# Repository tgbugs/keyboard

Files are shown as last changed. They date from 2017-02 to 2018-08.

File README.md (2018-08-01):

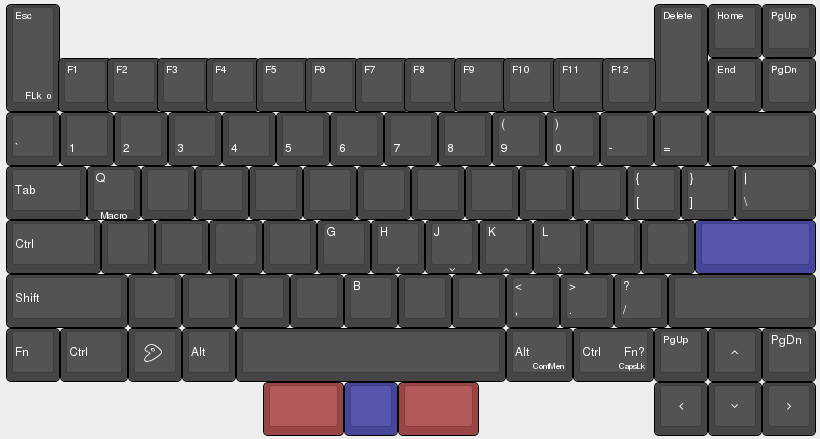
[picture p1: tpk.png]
current layout

# kicad libs and mods needed
https://github.com/tmk/kicad_lib_tmk.git
https://github.com/tmk/keyboard_parts.pretty
https://github.com/stormbard/Keyboard.pretty.git
https://github.com/XenGi/kicad_teensy.git
# use this guide
https://github.com/ruiqimao/keyboard-pcb-guide
# keyboard layout editor
https://github.com/swill/kb_builder
http://www.keyboard-layout-editor.com
# teensy setup on gentoo
Need dev-embedded/teensyduino and dev-embedded/teensy_loader_cli, working ebuilds in https://github.com/tgbugs/tgbugs-overlay.
# freerout is basically a necisity use this repo
https://github.com/nick-less/freerouting
Some setup needed to get maven to play nice. Just read the errors.
# gerbv
Before shipping out the gerber files do a once over in something other than kicad. `emerge gerbv`

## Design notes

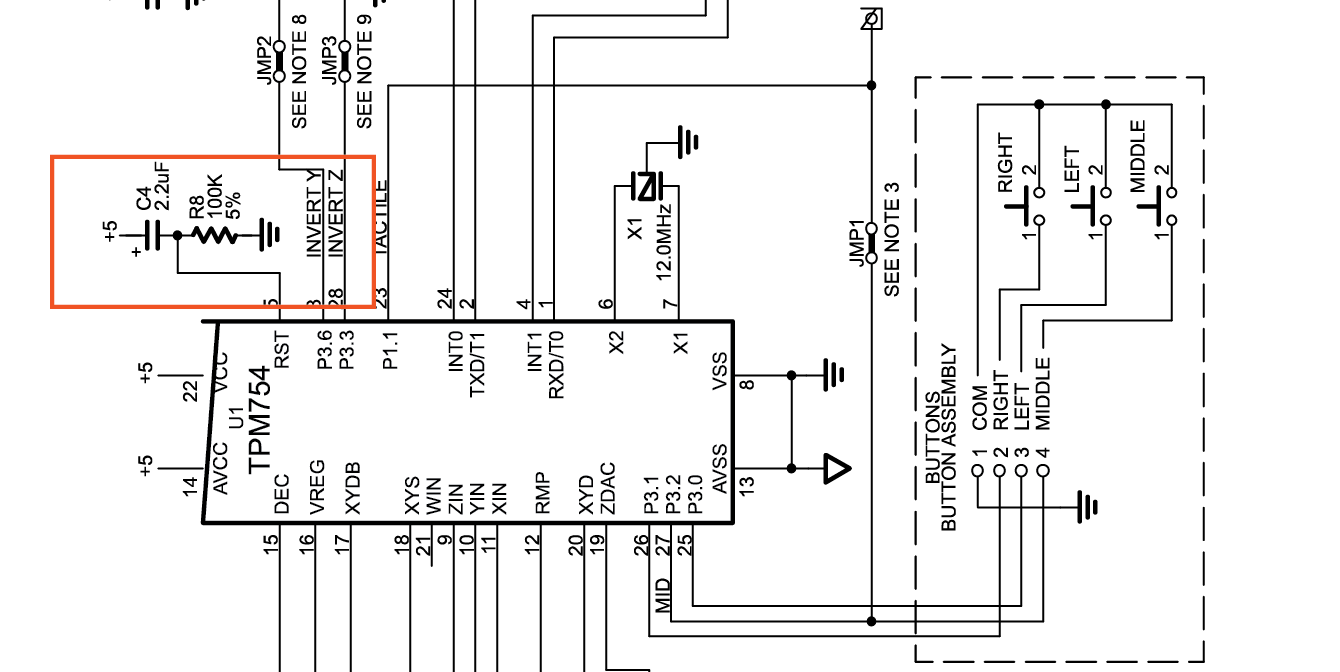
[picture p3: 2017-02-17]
doc/schematics/DSA1.png

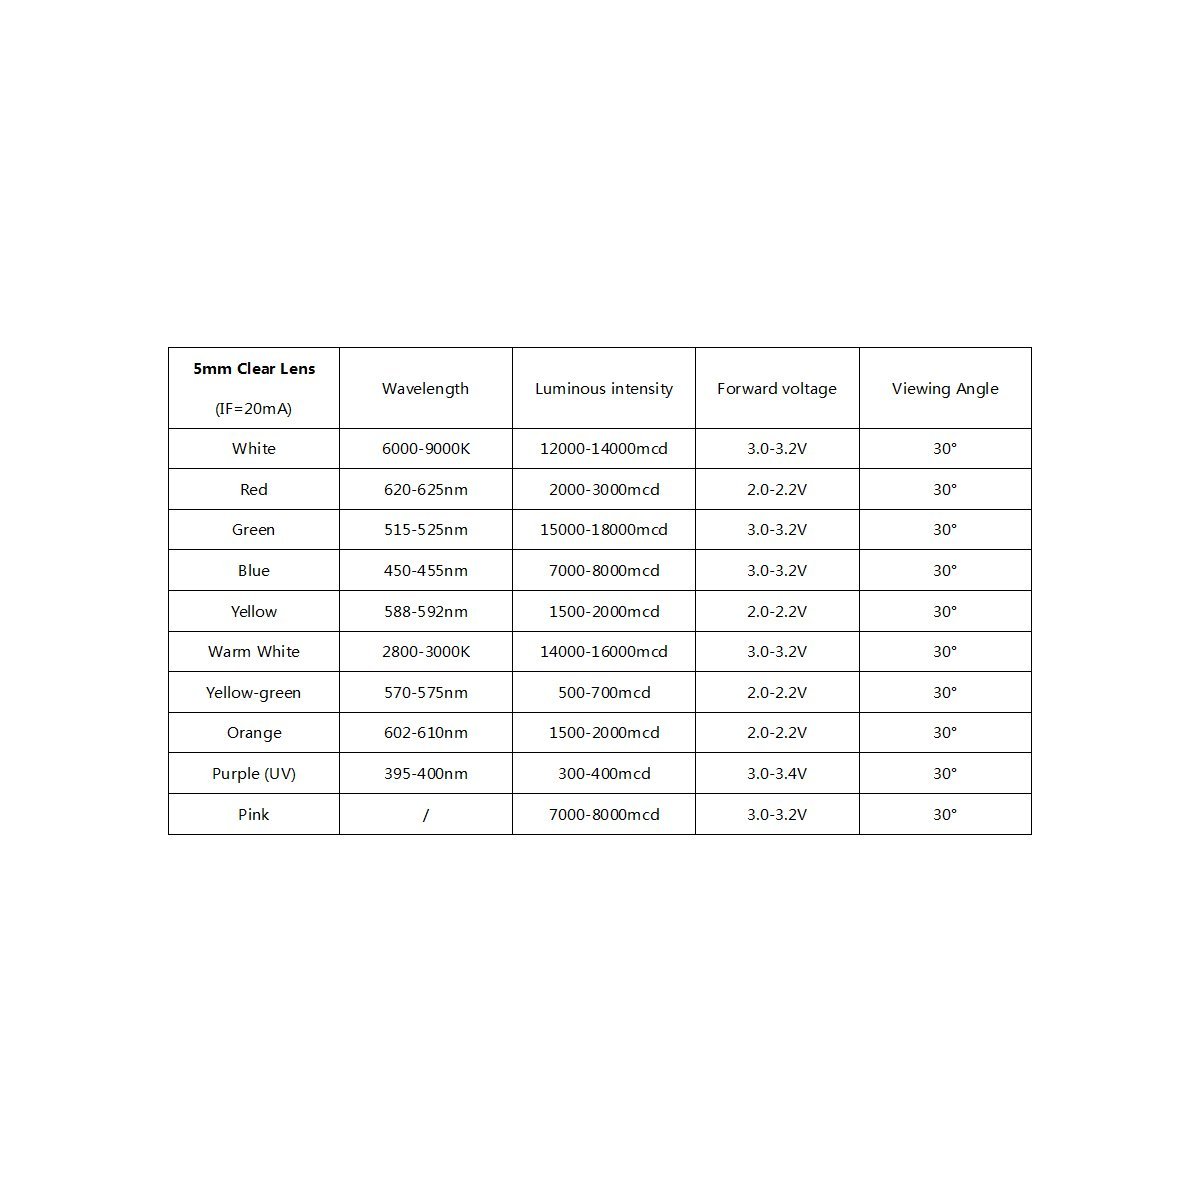
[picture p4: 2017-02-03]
doc/schematics/61HGZPv6i1L._SL1200_.jpg

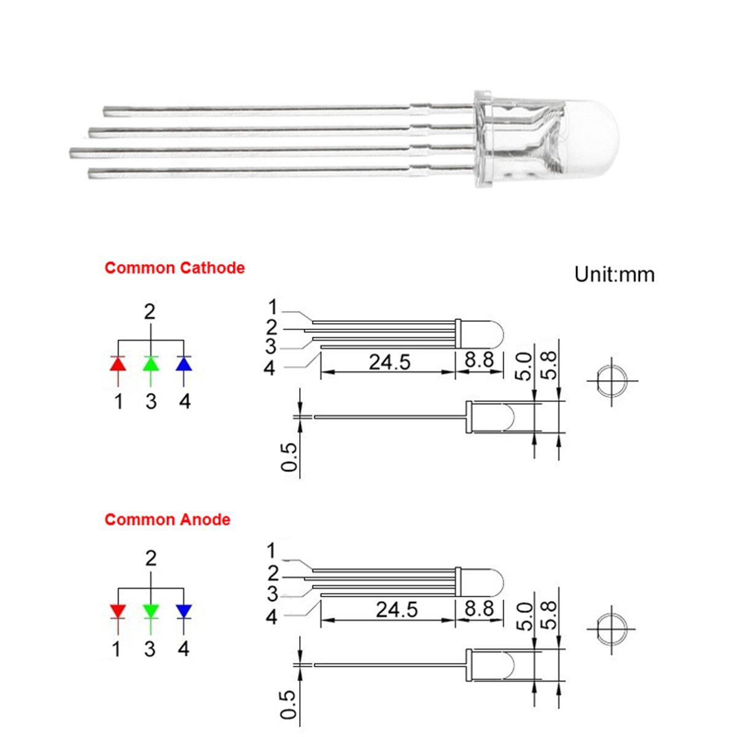
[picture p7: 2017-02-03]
doc/schematics/61A5xmcpJOL._SL1200_.jpg

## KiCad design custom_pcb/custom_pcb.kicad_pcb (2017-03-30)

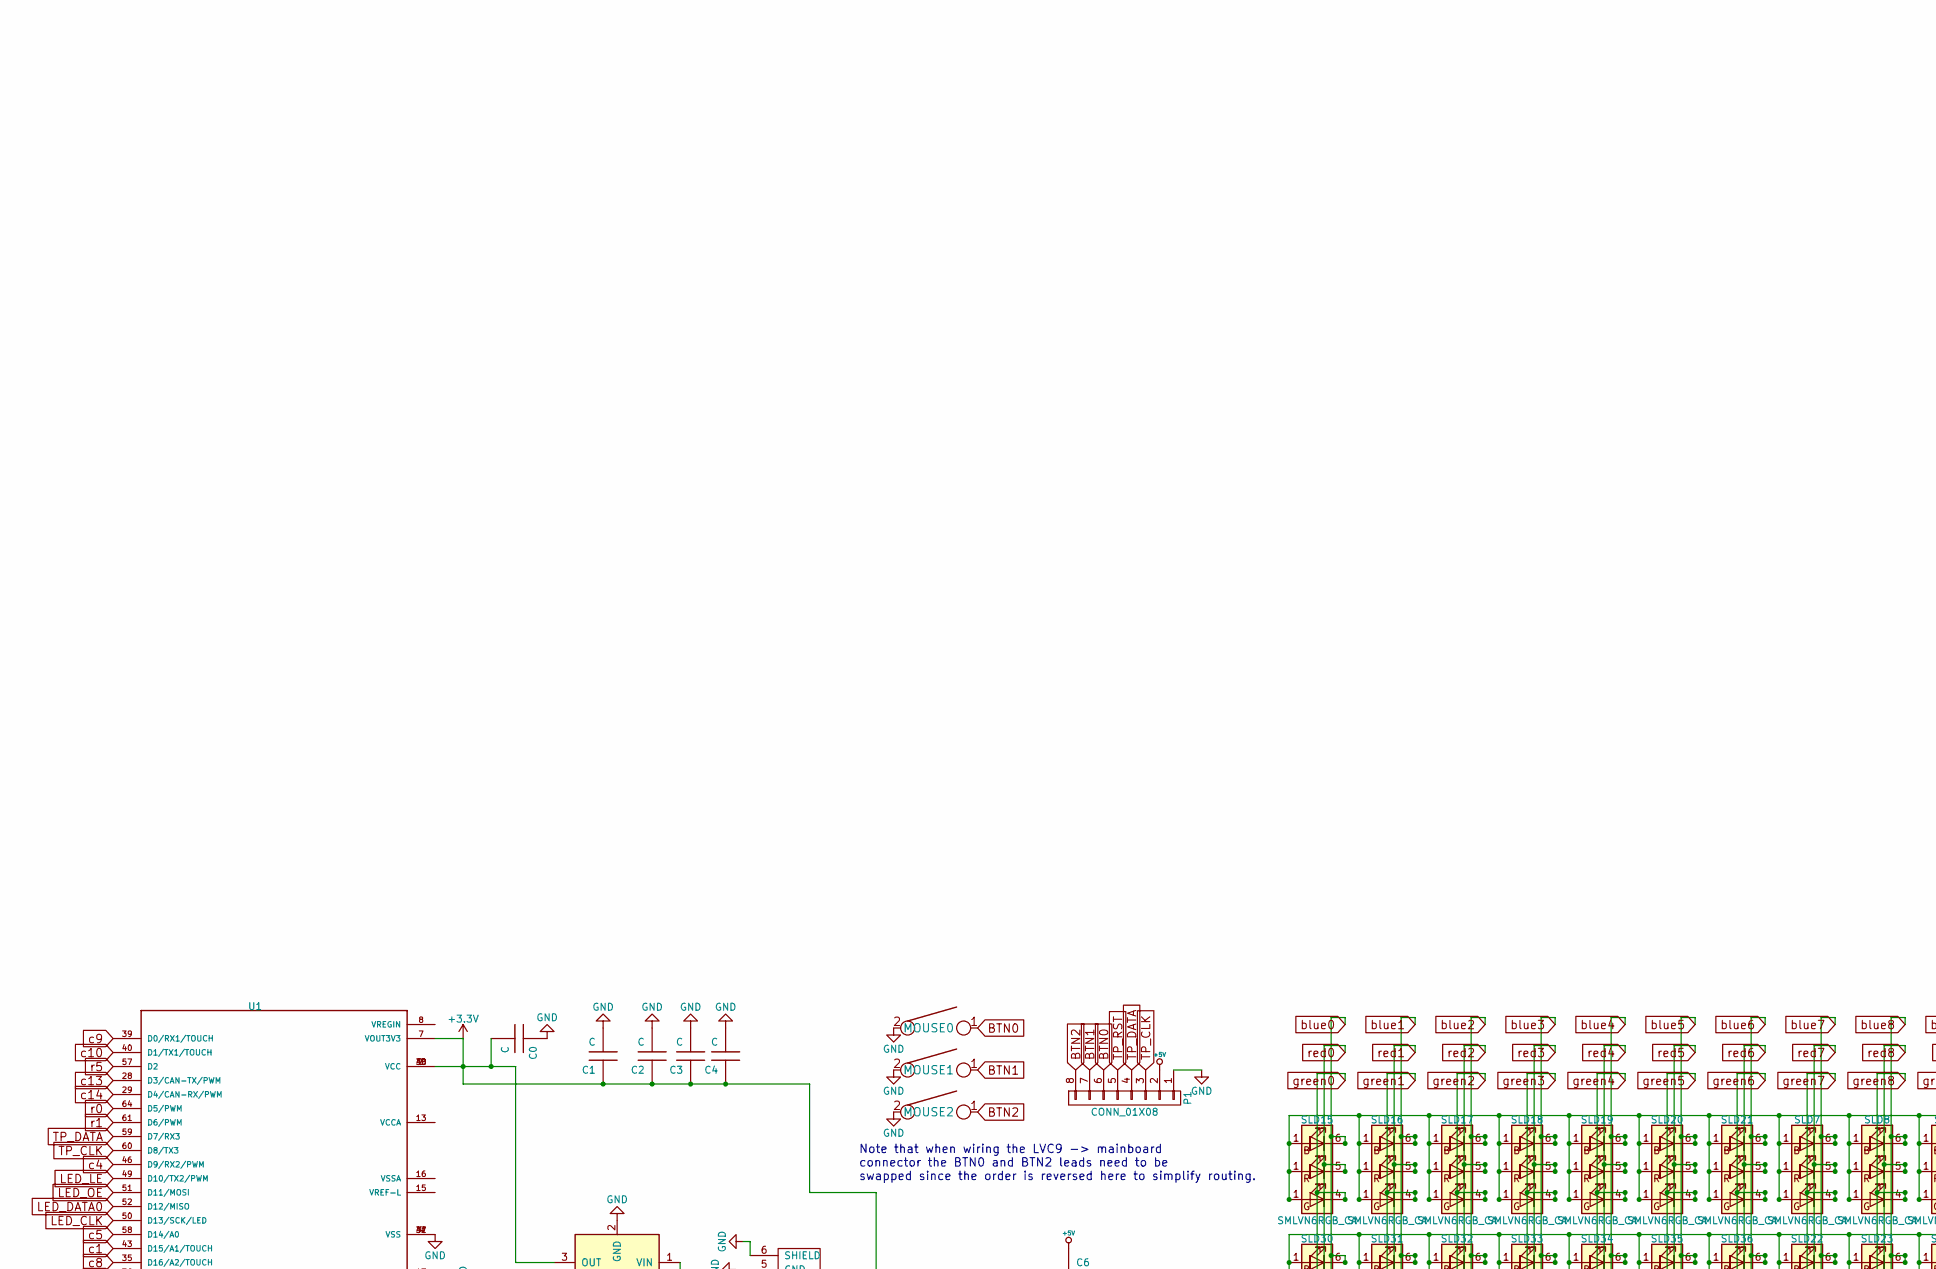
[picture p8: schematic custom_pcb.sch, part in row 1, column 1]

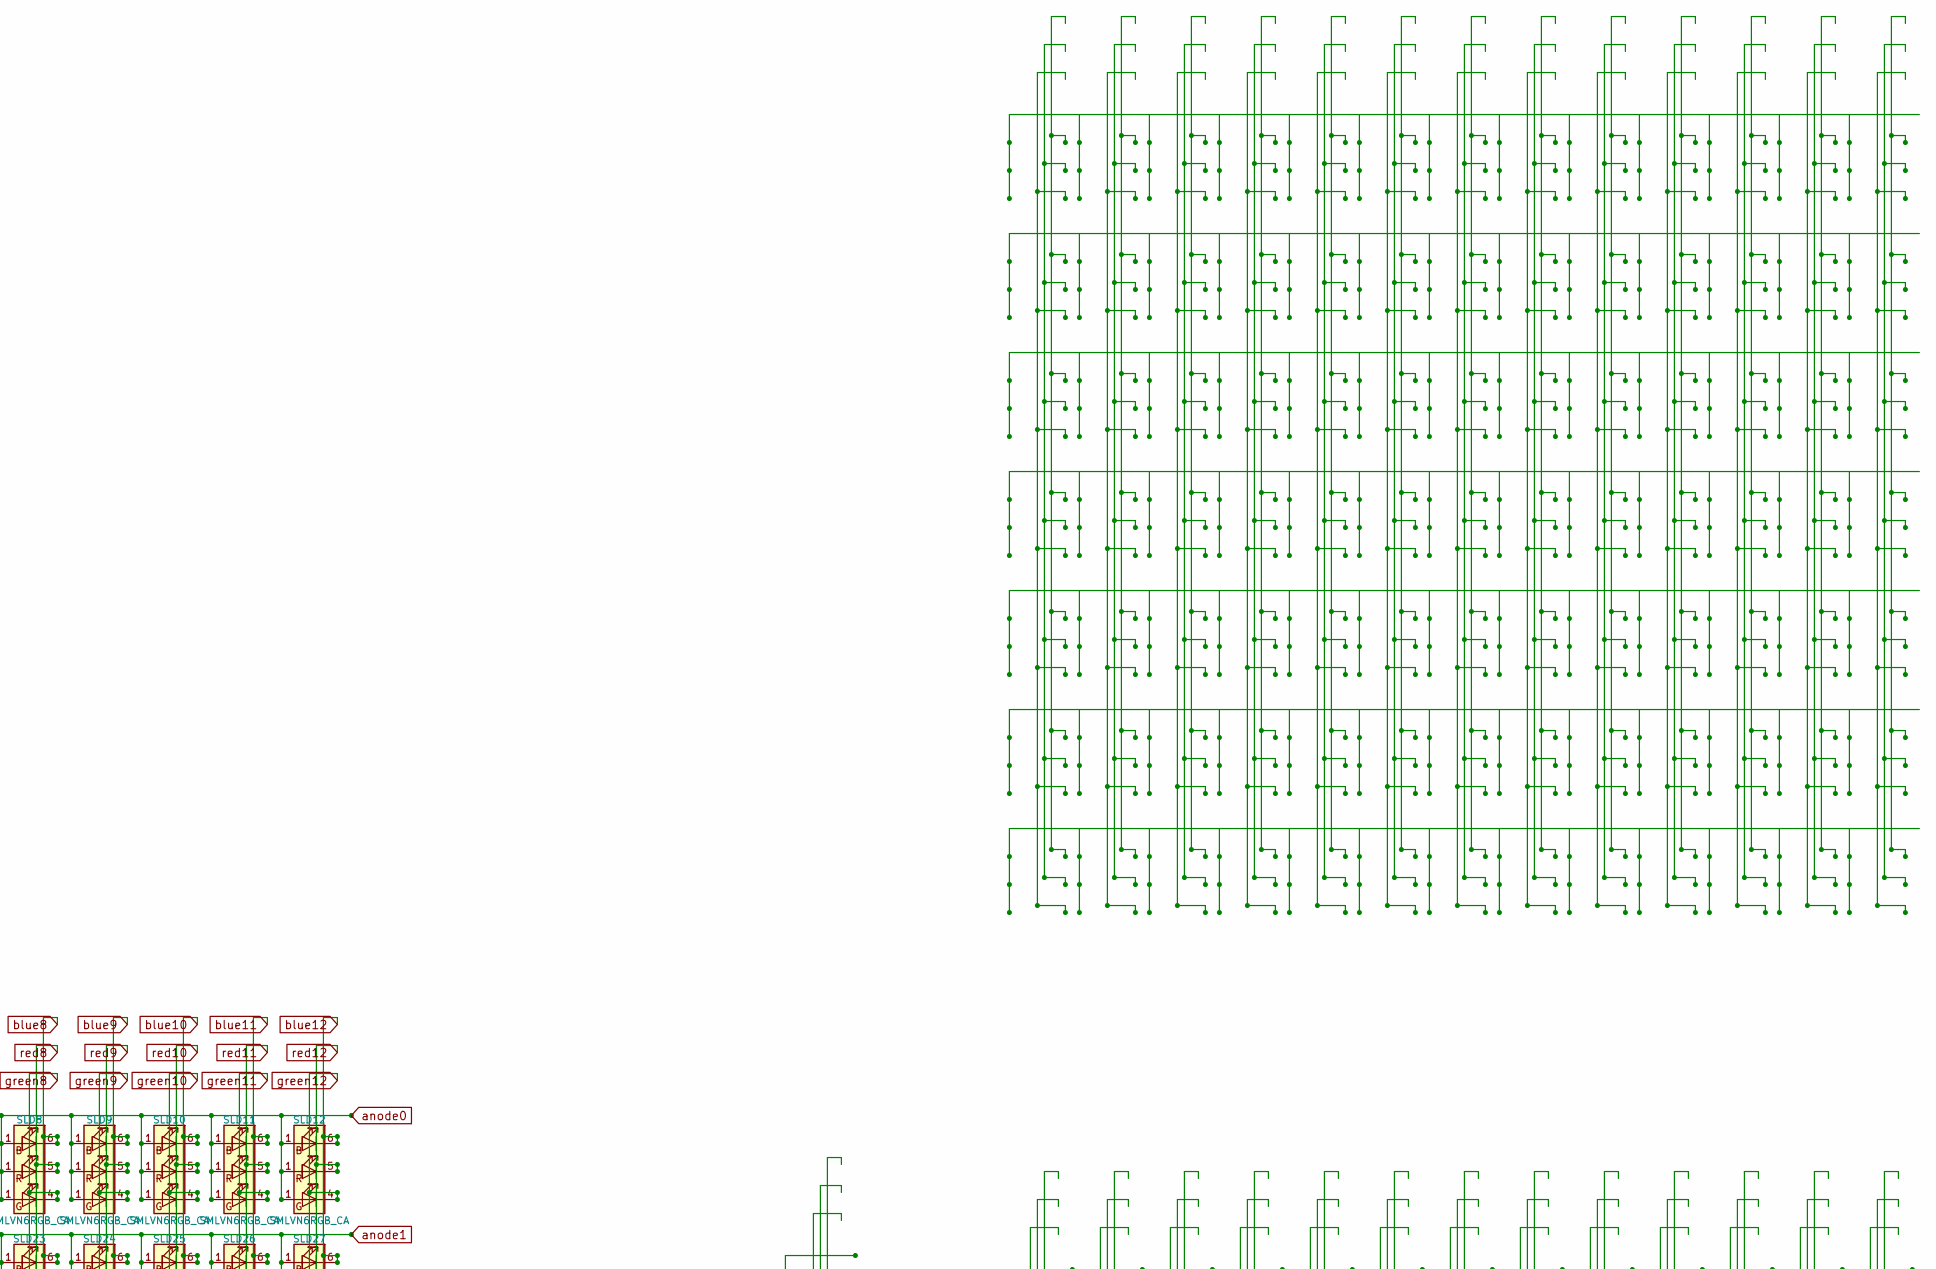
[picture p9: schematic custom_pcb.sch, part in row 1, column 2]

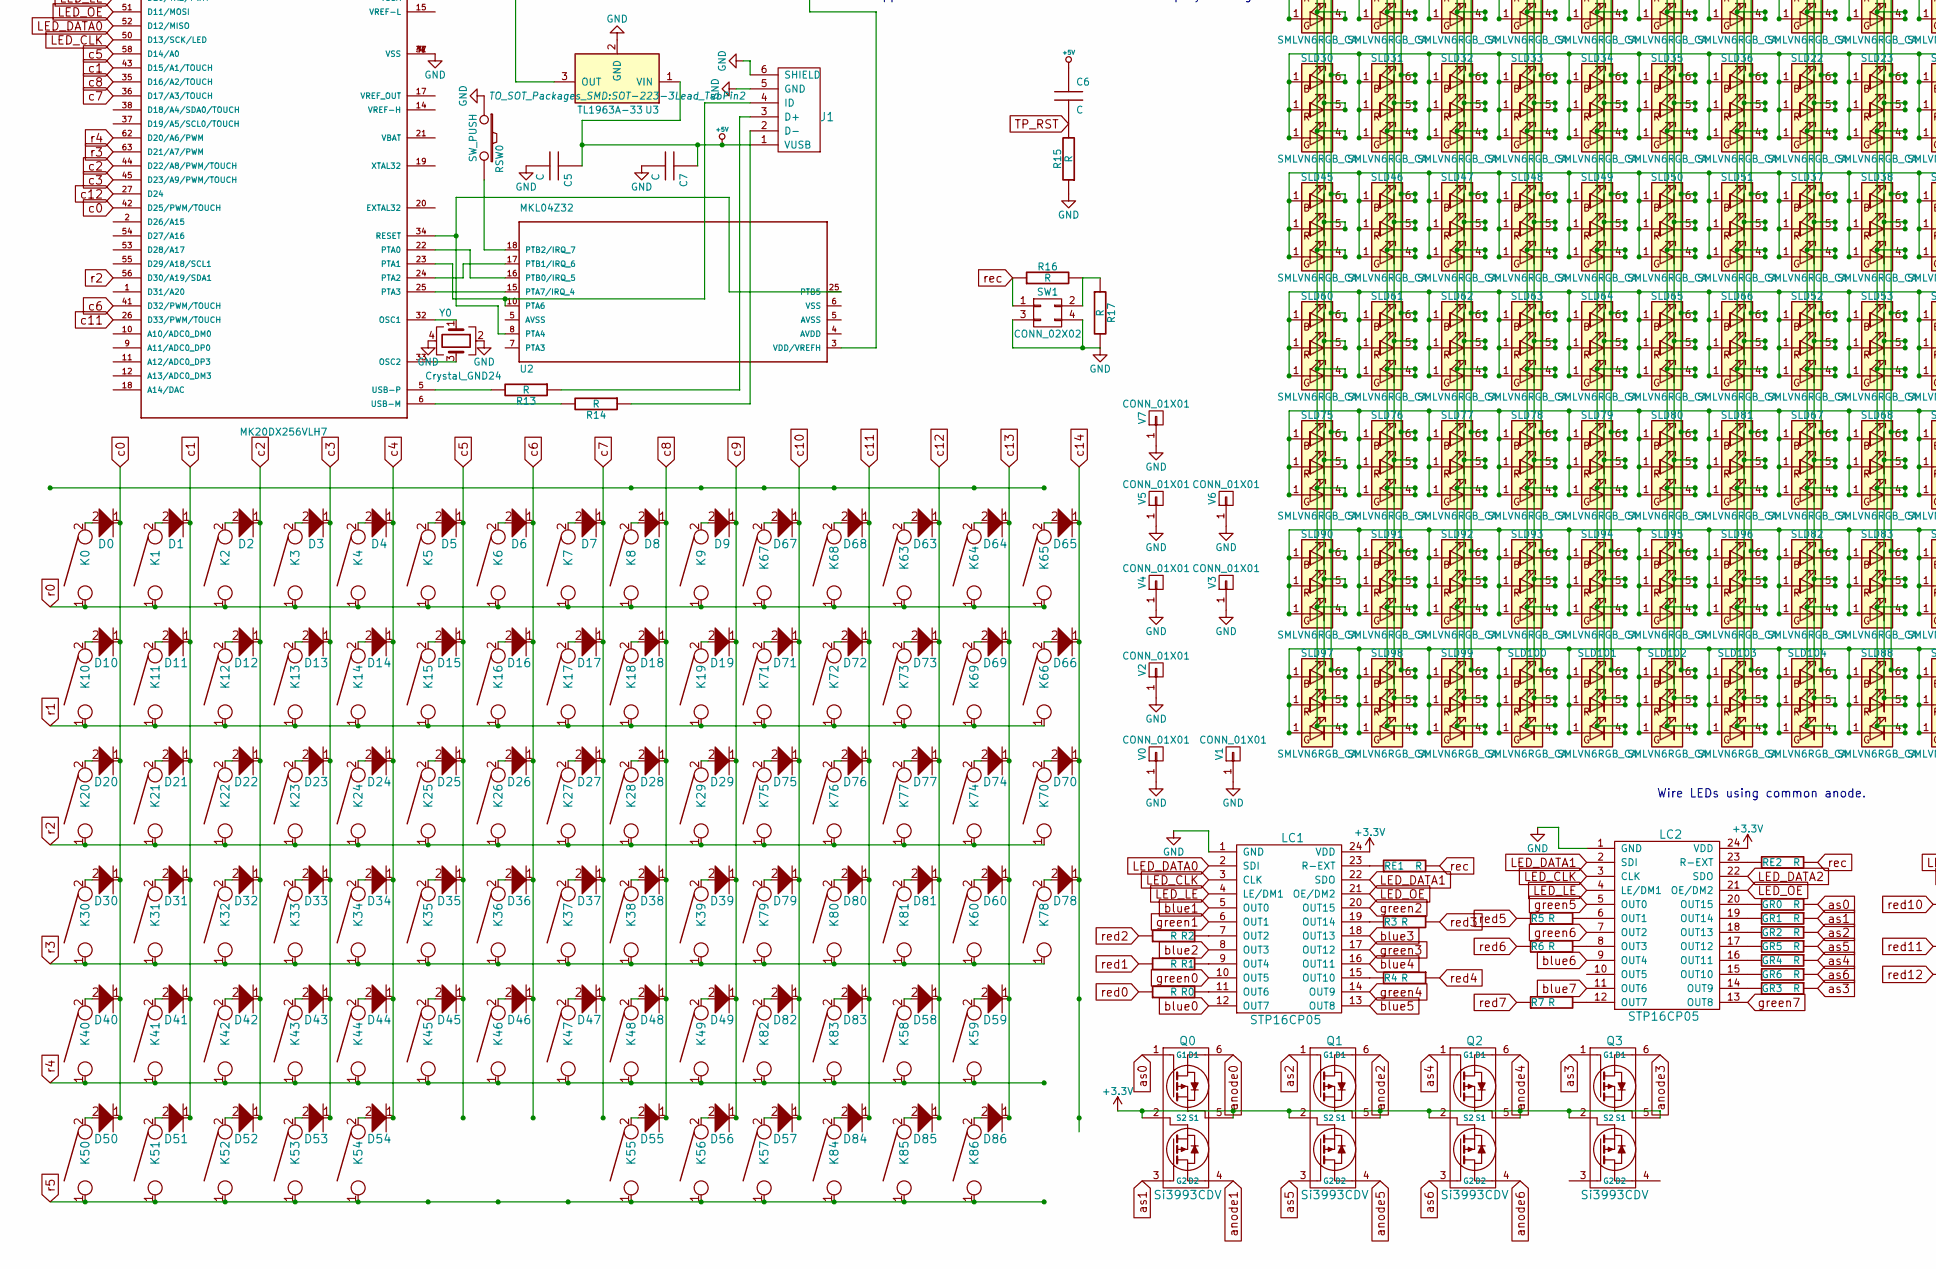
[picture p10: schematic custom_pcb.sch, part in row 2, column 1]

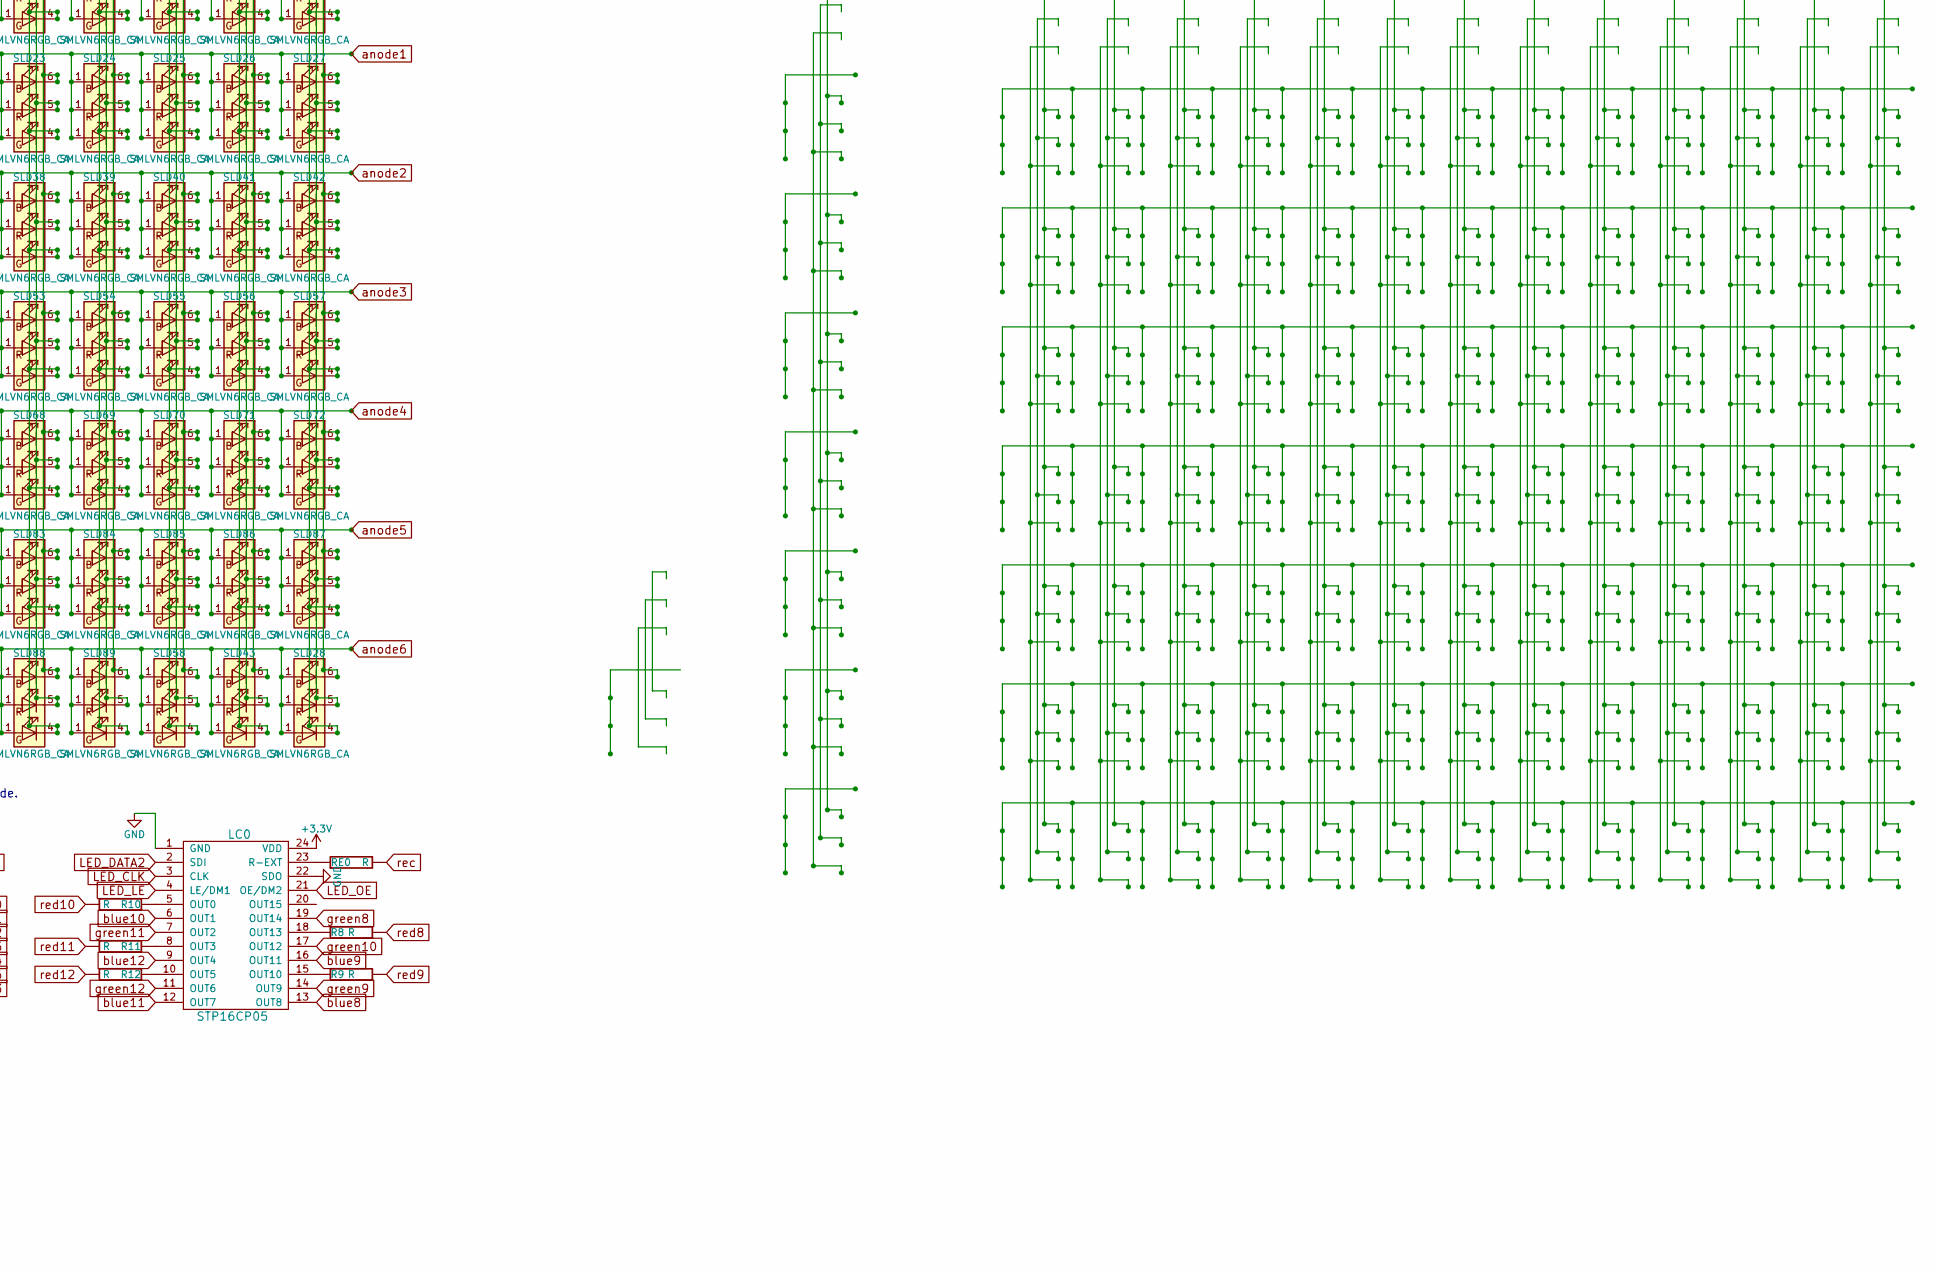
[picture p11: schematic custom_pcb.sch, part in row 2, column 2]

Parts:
C0, C1, C2, C3, C4, C5, C6, C7: C; C_0603_HandSoldering
D0, D1, D2, D3, D4, D5, D6, D7, D8, D9, D10, D11, D12, D13, D14, D15, D16, D17, D18, D19, D20, D21, D22, D23, D24, D25, D26, D27, D28, D29, D30, D31, D32, D33, D34, D35, D36, D37, D38, D39, D40, D41, D42, D43, D44, D45, D46, D47, D48, D49, D50, D51, D52, D53, D54, D55, D56, D57, D58, D59, D60, D63, D64, D65, D66, D67, D68, D69, D70, D71, D72, D73, D74, D75, D76, D77, D78, D79, D80, D81, D82, D83, D84, D85, D86: D; D_SOD-123
GR0, GR1, GR2, GR3, GR4, GR5, GR6: R; R_0402_NoSilk
J1: USB_mini_micro_B; USB_miniB_hirose_5S8
K0, K64: KEYSW; CHERRY_PLATE_200V
K1, K2, K3, K4, K5, K6, K7, K8, K9, K63, K67, K68: KEYSW; CHERRY_PLATE_91.6H
K10, K11, K12, K13, K14, K15, K16, K17, K18, K19, K21, K22, K23, K24, K25, K26, K27, K28, K29, K31, K32, K33, K34, K35, K36, K37, K38, K39, K41, K42, K43, K44, K45, K46, K47, K48, K49, K50, K52, K53, K57, K58, K59, K60, K65, K66, K69, K70, K71, K72, K73, K75, K76, K77, K79, K80, K82, K84, K85, K86: KEYSW; CHERRY_PLATE_100H
K20, K56, K78: KEYSW; CHERRY_PLATE_150H
K30: KEYSW; CHERRY_PLATE_175H
K40, K81: KEYSW; CHERRY_PLATE_225H
K51, K55: KEYSW; CHERRY_PLATE_125H
K54: KEYSW; CHERRY_PLATE_5000H
K74: KEYSW; CHERRY_PLATE_200H
K83: KEYSW; CHERRY_PLATE_175_275H
LC0, LC1, LC2: STP16CP05; TSSOP-24_4.4x7.8mm_Pitch0.65mm
MOUSE0, MOUSE2: KEYSW; CHERRY_PLATE_150H
MOUSE1: KEYSW; CHERRY_PLATE_100H
P1: CONN_01X08; Molex_PicoBlade_53261-0871_08x1.25mm_Angled
Q0, Q1, Q2, Q3: Si3993CDV; SOT-23-6_Handsoldering
R0, R1, R2, R3, R4, R5, R6, R7, R8, R9, R10, R11, R12, R13, R14, R15, R16, R17: R; R_0603_HandSoldering
RE0, RE1, RE2: R; R_0603_HandSoldering
RSW0: SW_PUSH; SW_SPST_B3U-1000P
SLD7, SLD8, SLD9, SLD10, SLD11, SLD12, SLD15, SLD16, SLD17, SLD18, SLD19, SLD20, SLD21, SLD22, SLD23, SLD24, SLD25, SLD26, SLD27, SLD28, SLD30, SLD31, SLD32, SLD33, SLD34, SLD35, SLD36, SLD37, SLD38, SLD39, SLD40, SLD41, SLD42, SLD43, SLD45, SLD46, SLD47, SLD48, SLD49, SLD50, SLD51, SLD52, SLD53, SLD54, SLD55, SLD56, SLD57, SLD58, SLD60, SLD61, SLD62, SLD63, SLD64, SLD65, SLD66, SLD67, SLD68, SLD69, SLD70, SLD71, SLD72, SLD75, SLD76, SLD77, SLD78, SLD79, SLD80, SLD81, SLD82, SLD83, SLD84, SLD85, SLD86, SLD87, SLD88, SLD89, SLD90, SLD91, SLD92, SLD93, SLD94, SLD95, SLD96, SLD97, SLD98, SLD99, SLD100, SLD101, SLD102, SLD103, SLD104: SMLVN6RGB_CA
SW1: CONN_02X02; CVS-02TB
U1: MK20DX256VLH7; QFP50P1200X1200X160-64N
U2: MKL04Z32; QFP50P900X900X160-48N
U3: TL1963A-33; SOT-223-3Lead_TabPin2
V0, V1, V2, V6: CONN_01X01; VIA100
V3, V4, V5, V7: CONN_01X01; VIA127
Y0: Crystal_GND24; Crystal_SMD_3225-4pin_3.2x2.5mm_HandSoldering

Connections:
+3V3: C0.2, C1.1, C2.1, C3.1, C4.1, LC0.24 (VDD), LC1.24 (VDD), LC2.24 (VDD), Q0.2 (S2), Q0.5 (S1), Q1.2 (S2), Q1.5 (S1), Q2.2 (S2), Q2.5 (S1), Q3.2 (S2), Q3.5 (S1), U1.3 (VCC), U1.7 (VOUT3V3), U1.30 (VCC), U1.48 (VCC), U2.3 (VDD/VREFH), U3.3 (OUT)
+5V: C5.1, C6.1, C7.1, J1.1 (VUSB), P1.2, U3.1 (VIN)
BTN0: MOUSE0.1, P1.6
BTN1: MOUSE1.1, P1.7
BTN2: MOUSE2.1, P1.8
GND: C0.1, C1.2, C2.2, C3.2, C4.2, C5.2, C7.2, J1.5 (GND), J1.6 (SHIELD), LC0.1 (GND), LC0.22 (SDO), LC1.1 (GND), LC2.1 (GND), MOUSE0.2, MOUSE1.2, MOUSE2.2, P1.1, R15.1, R17.2, RSW0.1, SW1.3, SW1.4, U1.4 (VSS), U1.31 (VSS), U1.47 (VSS), U3.2 (GND), V0.1, V1.1, V2.1, V3.1, V4.1, V5.1, V6.1, V7.1, Y0.2, Y0.4
LED_CLK: LC0.3 (CLK), LC1.3 (CLK), LC2.3 (CLK), U1.50 (D13/SCK/LED)
LED_DATA0: LC1.2 (SDI), U1.52 (D12/MISO)
LED_DATA1: LC1.22 (SDO), LC2.2 (SDI)
LED_DATA2: LC0.2 (SDI), LC2.22 (SDO)
LED_LE: LC0.4 (LE/DM1), LC1.4 (LE/DM1), LC2.4 (LE/DM1), U1.49 (D10/TX2/PWM)
LED_OE: LC0.21 (OE/DM2), LC1.21 (OE/DM2), LC2.21 (OE/DM2), U1.51 (D11/MOSI)
unnamed: D0.2, K0.2
unnamed: D1.2, K1.2
unnamed: D2.2, K2.2
unnamed: D3.2, K3.2
unnamed: D4.2, K4.2
unnamed: D5.2, K5.2
unnamed: D6.2, K6.2
unnamed: D7.2, K7.2
unnamed: D8.2, K8.2
unnamed: D9.2, K9.2
unnamed: D10.2, K10.2
unnamed: D11.2, K11.2
unnamed: D12.2, K12.2
unnamed: D13.2, K13.2
unnamed: D14.2, K14.2
unnamed: D15.2, K15.2
unnamed: D16.2, K16.2
unnamed: D17.2, K17.2
unnamed: D18.2, K18.2
unnamed: D19.2, K19.2
unnamed: D20.2, K20.2
unnamed: D21.2, K21.2
unnamed: D22.2, K22.2
unnamed: D23.2, K23.2
unnamed: D24.2, K24.2
unnamed: D25.2, K25.2
unnamed: D26.2, K26.2
unnamed: D27.2, K27.2
unnamed: D28.2, K28.2
unnamed: D29.2, K29.2
unnamed: D30.2, K30.2
unnamed: D31.2, K31.2
unnamed: D32.2, K32.2
unnamed: D33.2, K33.2
unnamed: D34.2, K34.2
unnamed: D35.2, K35.2
unnamed: D36.2, K36.2
unnamed: D37.2, K37.2
unnamed: D38.2, K38.2
unnamed: D39.2, K39.2
unnamed: D40.2, K40.2
unnamed: D41.2, K41.2
unnamed: D42.2, K42.2
unnamed: D43.2, K43.2
unnamed: D44.2, K44.2
unnamed: D45.2, K45.2
unnamed: D46.2, K46.2
unnamed: D47.2, K47.2
unnamed: D48.2, K48.2
unnamed: D49.2, K49.2
unnamed: D50.2, K50.2
unnamed: D51.2, K51.2
unnamed: D52.2, K52.2
unnamed: D53.2, K53.2
unnamed: D54.2, K54.2
unnamed: D55.2, K55.2
unnamed: D56.2, K56.2
unnamed: D57.2, K57.2
unnamed: D58.2, K58.2
unnamed: D59.2, K59.2
unnamed: D60.2, K60.2
unnamed: D63.2, K63.2
unnamed: D64.2, K64.2
unnamed: D65.2, K65.2
unnamed: D66.2, K66.2
unnamed: D67.2, K67.2
unnamed: D68.2, K68.2
unnamed: D69.2, K69.2
unnamed: D70.2, K70.2
unnamed: D71.2, K71.2
unnamed: D72.2, K72.2
unnamed: D73.2, K73.2
unnamed: D74.2, K74.2
unnamed: D75.2, K75.2
unnamed: D76.2, K76.2
unnamed: D77.2, K77.2
unnamed: D78.2, K78.2
unnamed: D79.2, K79.2
unnamed: D80.2, K80.2
unnamed: D81.2, K81.2
unnamed: D82.2, K82.2
unnamed: D83.2, K83.2
unnamed: D84.2, K84.2
unnamed: D85.2, K85.2
unnamed: D86.2, K86.2
unnamed: GR0.2, LC2.20 (OUT15)
unnamed: GR1.2, LC2.19 (OUT14)
unnamed: GR2.2, LC2.18 (OUT13)
unnamed: GR3.2, LC2.14 (OUT9)
unnamed: GR4.2, LC2.16 (OUT11)
unnamed: GR5.2, LC2.17 (OUT12)
unnamed: GR6.2, LC2.15 (OUT10)
unnamed: J1.2 (D-), R14.1
unnamed: J1.3 (D+), R13.1
unnamed: J1.4 (ID), U1.23 (PTA1), U2.10 (PTA6)
unnamed: LC0.5 (OUT0), R10.1
unnamed: LC0.8 (OUT3), R11.1
unnamed: LC0.10 (OUT5), R12.1
unnamed: LC0.15 (OUT10), R9.1
unnamed: LC0.18 (OUT13), R8.1
unnamed: LC0.23 (R-EXT), RE0.1
unnamed: LC1.7 (OUT2), R2.2
unnamed: LC1.9 (OUT4), R1.2
unnamed: LC1.11 (OUT6), R0.2
unnamed: LC1.15 (OUT10), R4.2
unnamed: LC1.19 (OUT14), R3.2
unnamed: LC1.23 (R-EXT), RE1.1
unnamed: LC2.6 (OUT1), R5.2
unnamed: LC2.8 (OUT3), R6.2
unnamed: LC2.12 (OUT7), R7.2
unnamed: LC2.23 (R-EXT), RE2.1
unnamed: R13.2, U1.5 (USB-P)
unnamed: R14.2, U1.6 (USB-M)
unnamed: R16.2, R17.1, SW1.2
unnamed: RSW0.2, U2.18 (PTB2/IRQ_7)
unnamed: U1.22 (PTA0), U2.16 (PTB0/IRQ_5)
unnamed: U1.24 (PTA2), U2.17 (PTB1/IRQ_6)
unnamed: U1.25 (PTA3), U2.15 (PTA7/IRQ_4)
unnamed: U1.32 (OSC1), Y0.1
unnamed: U1.33 (OSC2), Y0.3
unnamed: U1.34 (RESET), U2.8 (PTA4), U2.25 (PTB5)
TP_CLK: P1.3, U1.60 (D8/TX3)
TP_DATA: P1.4, U1.59 (D7/RX3)
TP_RST: C6.2, P1.5, R15.2
anode0: Q0.6 (D1), SLD7.1 (BK), SLD8.1 (BK), SLD9.1 (BK), SLD10.1 (BK), SLD11.1 (BK), SLD12.1 (BK), SLD15.1 (BK), SLD16.1 (BK), SLD17.1 (BK), SLD18.1 (BK), SLD19.1 (BK), SLD20.1 (BK), SLD21.1 (BK)
anode1: Q0.4 (D2), SLD22.1 (BK), SLD23.1 (BK), SLD24.1 (BK), SLD25.1 (BK), SLD26.1 (BK), SLD27.1 (BK), SLD30.1 (BK), SLD31.1 (BK), SLD32.1 (BK), SLD33.1 (BK), SLD34.1 (BK), SLD35.1 (BK), SLD36.1 (BK)
anode2: Q1.6 (D1), SLD37.1 (BK), SLD38.1 (BK), SLD39.1 (BK), SLD40.1 (BK), SLD41.1 (BK), SLD42.1 (BK), SLD45.1 (BK), SLD46.1 (BK), SLD47.1 (BK), SLD48.1 (BK), SLD49.1 (BK), SLD50.1 (BK), SLD51.1 (BK)
anode3: Q3.6 (D1), SLD52.1 (BK), SLD53.1 (BK), SLD54.1 (BK), SLD55.1 (BK), SLD56.1 (BK), SLD57.1 (BK), SLD60.1 (BK), SLD61.1 (BK), SLD62.1 (BK), SLD63.1 (BK), SLD64.1 (BK), SLD65.1 (BK), SLD66.1 (BK)
anode4: Q2.6 (D1), SLD67.1 (BK), SLD68.1 (BK), SLD69.1 (BK), SLD70.1 (BK), SLD71.1 (BK), SLD72.1 (BK), SLD75.1 (BK), SLD76.1 (BK), SLD77.1 (BK), SLD78.1 (BK), SLD79.1 (BK), SLD80.1 (BK), SLD81.1 (BK)
anode5: Q1.4 (D2), SLD82.1 (BK), SLD83.1 (BK), SLD84.1 (BK), SLD85.1 (BK), SLD86.1 (BK), SLD87.1 (BK), SLD90.1 (BK), SLD91.1 (BK), SLD92.1 (BK), SLD93.1 (BK), SLD94.1 (BK), SLD95.1 (BK), SLD96.1 (BK)
anode6: Q2.4 (D2), SLD28.1 (BK), SLD43.1 (BK), SLD58.1 (BK), SLD88.1 (BK), SLD89.1 (BK), SLD97.1 (BK), SLD98.1 (BK), SLD99.1 (BK), SLD100.1 (BK), SLD101.1 (BK), SLD102.1 (BK), SLD103.1 (BK), SLD104.1 (BK)
as0: GR0.1, Q0.1 (G1)
as1: GR1.1, Q0.3 (G2)
as2: GR2.1, Q1.1 (G1)
as3: GR3.1, Q3.1 (G1)
as4: GR4.1, Q2.1 (G1)
as5: GR5.1, Q1.3 (G2)
as6: GR6.1, Q2.3 (G2)
blue0: LC1.12 (OUT7), SLD15.6 (RA), SLD30.6 (RA), SLD45.6 (RA), SLD60.6 (RA), SLD75.6 (RA), SLD90.6 (RA), SLD97.6 (RA)
blue1: LC1.5 (OUT0), SLD16.6 (RA), SLD31.6 (RA), SLD46.6 (RA), SLD61.6 (RA), SLD76.6 (RA), SLD91.6 (RA), SLD98.6 (RA)
blue2: LC1.8 (OUT3), SLD17.6 (RA), SLD32.6 (RA), SLD47.6 (RA), SLD62.6 (RA), SLD77.6 (RA), SLD92.6 (RA), SLD99.6 (RA)
blue3: LC1.18 (OUT13), SLD18.6 (RA), SLD33.6 (RA), SLD48.6 (RA), SLD63.6 (RA), SLD78.6 (RA), SLD93.6 (RA), SLD100.6 (RA)
blue4: LC1.16 (OUT11), SLD19.6 (RA), SLD34.6 (RA), SLD49.6 (RA), SLD64.6 (RA), SLD79.6 (RA), SLD94.6 (RA), SLD101.6 (RA)
blue5: LC1.13 (OUT8), SLD20.6 (RA), SLD35.6 (RA), SLD50.6 (RA), SLD65.6 (RA), SLD80.6 (RA), SLD95.6 (RA), SLD102.6 (RA)
blue6: LC2.9 (OUT4), SLD21.6 (RA), SLD36.6 (RA), SLD51.6 (RA), SLD66.6 (RA), SLD81.6 (RA), SLD96.6 (RA), SLD103.6 (RA)
blue7: LC2.11 (OUT6), SLD7.6 (RA), SLD22.6 (RA), SLD37.6 (RA), SLD52.6 (RA), SLD67.6 (RA), SLD82.6 (RA), SLD104.6 (RA)
blue8: LC0.13 (OUT8), SLD8.6 (RA), SLD23.6 (RA), SLD38.6 (RA), SLD53.6 (RA), SLD68.6 (RA), SLD83.6 (RA), SLD88.6 (RA)
blue9: LC0.16 (OUT11), SLD9.6 (RA), SLD24.6 (RA), SLD39.6 (RA), SLD54.6 (RA), SLD69.6 (RA), SLD84.6 (RA), SLD89.6 (RA)
blue10: LC0.6 (OUT1), SLD10.6 (RA), SLD25.6 (RA), SLD40.6 (RA), SLD55.6 (RA), SLD58.6 (RA), SLD70.6 (RA), SLD85.6 (RA)
blue11: LC0.12 (OUT7), SLD11.6 (RA), SLD26.6 (RA), SLD41.6 (RA), SLD43.6 (RA), SLD56.6 (RA), SLD71.6 (RA), SLD86.6 (RA)
blue12: LC0.9 (OUT4), SLD12.6 (RA), SLD27.6 (RA), SLD28.6 (RA), SLD42.6 (RA), SLD57.6 (RA), SLD72.6 (RA), SLD87.6 (RA)
c0: D0.1, D10.1, D20.1, D30.1, D40.1, D50.1, U1.42 (D25/PWM/TOUCH)
c1: D1.1, D11.1, D21.1, D31.1, D41.1, D51.1, U1.43 (D15/A1/TOUCH)
c2: D2.1, D12.1, D22.1, D32.1, D42.1, D52.1, U1.44 (D22/A8/PWM/TOUCH)
c3: D3.1, D13.1, D23.1, D33.1, D43.1, D53.1, U1.45 (D23/A9/PWM/TOUCH)
c4: D4.1, D14.1, D24.1, D34.1, D44.1, D54.1, U1.46 (D9/RX2/PWM)
c5: D5.1, D15.1, D25.1, D35.1, D45.1, U1.58 (D14/A0)
c6: D6.1, D16.1, D26.1, D36.1, D46.1, U1.41 (D32/PWM/TOUCH)
c7: D7.1, D17.1, D27.1, D37.1, D47.1, U1.36 (D17/A3/TOUCH)
c8: D8.1, D18.1, D28.1, D38.1, D48.1, D55.1, U1.35 (D16/A2/TOUCH)
c9: D9.1, D19.1, D29.1, D39.1, D49.1, D56.1, U1.39 (D0/RX1/TOUCH)
c10: D57.1, D67.1, D71.1, D75.1, D79.1, D82.1, U1.40 (D1/TX1/TOUCH)
c11: D68.1, D72.1, D76.1, D80.1, D83.1, D84.1, U1.26 (D33/PWM/TOUCH)
c12: D58.1, D63.1, D73.1, D77.1, D81.1, D85.1, U1.27 (D24)
c13: D59.1, D60.1, D64.1, D69.1, D74.1, D86.1, U1.28 (D3/CAN-TX/PWM)
c14: D65.1, D66.1, D70.1, D78.1, U1.29 (D4/CAN-RX/PWM)
green0: LC1.10 (OUT5), SLD15.4 (BA), SLD30.4 (BA), SLD45.4 (BA), SLD60.4 (BA), SLD75.4 (BA), SLD90.4 (BA), SLD97.4 (BA)
green1: LC1.6 (OUT1), SLD16.4 (BA), SLD31.4 (BA), SLD46.4 (BA), SLD61.4 (BA), SLD76.4 (BA), SLD91.4 (BA), SLD98.4 (BA)
green2: LC1.20 (OUT15), SLD17.4 (BA), SLD32.4 (BA), SLD47.4 (BA), SLD62.4 (BA), SLD77.4 (BA), SLD92.4 (BA), SLD99.4 (BA)
green3: LC1.17 (OUT12), SLD18.4 (BA), SLD33.4 (BA), SLD48.4 (BA), SLD63.4 (BA), SLD78.4 (BA), SLD93.4 (BA), SLD100.4 (BA)
green4: LC1.14 (OUT9), SLD19.4 (BA), SLD34.4 (BA), SLD49.4 (BA), SLD64.4 (BA), SLD79.4 (BA), SLD94.4 (BA), SLD101.4 (BA)
green5: LC2.5 (OUT0), SLD20.4 (BA), SLD35.4 (BA), SLD50.4 (BA), SLD65.4 (BA), SLD80.4 (BA), SLD95.4 (BA), SLD102.4 (BA)
green6: LC2.7 (OUT2), SLD21.4 (BA), SLD36.4 (BA), SLD51.4 (BA), SLD66.4 (BA), SLD81.4 (BA), SLD96.4 (BA), SLD103.4 (BA)
green7: LC2.13 (OUT8), SLD7.4 (BA), SLD22.4 (BA), SLD37.4 (BA), SLD52.4 (BA), SLD67.4 (BA), SLD82.4 (BA), SLD104.4 (BA)
green8: LC0.19 (OUT14), SLD8.4 (BA), SLD23.4 (BA), SLD38.4 (BA), SLD53.4 (BA), SLD68.4 (BA), SLD83.4 (BA), SLD88.4 (BA)
green9: LC0.14 (OUT9), SLD9.4 (BA), SLD24.4 (BA), SLD39.4 (BA), SLD54.4 (BA), SLD69.4 (BA), SLD84.4 (BA), SLD89.4 (BA)
green10: LC0.17 (OUT12), SLD10.4 (BA), SLD25.4 (BA), SLD40.4 (BA), SLD55.4 (BA), SLD58.4 (BA), SLD70.4 (BA), SLD85.4 (BA)
green11: LC0.7 (OUT2), SLD11.4 (BA), SLD26.4 (BA), SLD41.4 (BA), SLD43.4 (BA), SLD56.4 (BA), SLD71.4 (BA), SLD86.4 (BA)
green12: LC0.11 (OUT6), SLD12.4 (BA), SLD27.4 (BA), SLD28.4 (BA), SLD42.4 (BA), SLD57.4 (BA), SLD72.4 (BA), SLD87.4 (BA)
r0: K0.1, K1.1, K2.1, K3.1, K4.1, K5.1, K6.1, K7.1, K8.1, K9.1, K63.1, K64.1, K65.1, K67.1, K68.1, U1.64 (D5/PWM)
r1: K10.1, K11.1, K12.1, K13.1, K14.1, K15.1, K16.1, K17.1, K18.1, K19.1, K66.1, K69.1, K71.1, K72.1, K73.1, U1.61 (D6/PWM)
r2: K20.1, K21.1, K22.1, K23.1, K24.1, K25.1, K26.1, K27.1, K28.1, K29.1, K70.1, K74.1, K75.1, K76.1, K77.1, U1.56 (D30/A19/SDA1)
r3: K30.1, K31.1, K32.1, K33.1, K34.1, K35.1, K36.1, K37.1, K38.1, K39.1, K60.1, K78.1, K79.1, K80.1, K81.1, U1.63 (D21/A7/PWM)
r4: K40.1, K41.1, K42.1, K43.1, K44.1, K45.1, K46.1, K47.1, K48.1, K49.1, K58.1, K59.1, K82.1, K83.1, U1.62 (D20/A6/PWM)
r5: K50.1, K51.1, K52.1, K53.1, K54.1, K55.1, K56.1, K57.1, K84.1, K85.1, K86.1, U1.57 (D2)
rec: R16.1, RE0.2, RE1.2, RE2.2, SW1.1
red0: R0.1, SLD15.5 (GA), SLD30.5 (GA), SLD45.5 (GA), SLD60.5 (GA), SLD75.5 (GA), SLD90.5 (GA), SLD97.5 (GA)
red1: R1.1, SLD16.5 (GA), SLD31.5 (GA), SLD46.5 (GA), SLD61.5 (GA), SLD76.5 (GA), SLD91.5 (GA), SLD98.5 (GA)
red2: R2.1, SLD17.5 (GA), SLD32.5 (GA), SLD47.5 (GA), SLD62.5 (GA), SLD77.5 (GA), SLD92.5 (GA), SLD99.5 (GA)
red3: R3.1, SLD18.5 (GA), SLD33.5 (GA), SLD48.5 (GA), SLD63.5 (GA), SLD78.5 (GA), SLD93.5 (GA), SLD100.5 (GA)
red4: R4.1, SLD19.5 (GA), SLD34.5 (GA), SLD49.5 (GA), SLD64.5 (GA), SLD79.5 (GA), SLD94.5 (GA), SLD101.5 (GA)
red5: R5.1, SLD20.5 (GA), SLD35.5 (GA), SLD50.5 (GA), SLD65.5 (GA), SLD80.5 (GA), SLD95.5 (GA), SLD102.5 (GA)
red6: R6.1, SLD21.5 (GA), SLD36.5 (GA), SLD51.5 (GA), SLD66.5 (GA), SLD81.5 (GA), SLD96.5 (GA), SLD103.5 (GA)
red7: R7.1, SLD7.5 (GA), SLD22.5 (GA), SLD37.5 (GA), SLD52.5 (GA), SLD67.5 (GA), SLD82.5 (GA), SLD104.5 (GA)
red8: R8.2, SLD8.5 (GA), SLD23.5 (GA), SLD38.5 (GA), SLD53.5 (GA), SLD68.5 (GA), SLD83.5 (GA), SLD88.5 (GA)
red9: R9.2, SLD9.5 (GA), SLD24.5 (GA), SLD39.5 (GA), SLD54.5 (GA), SLD69.5 (GA), SLD84.5 (GA), SLD89.5 (GA)
red10: R10.2, SLD10.5 (GA), SLD25.5 (GA), SLD40.5 (GA), SLD55.5 (GA), SLD58.5 (GA), SLD70.5 (GA), SLD85.5 (GA)
red11: R11.2, SLD11.5 (GA), SLD26.5 (GA), SLD41.5 (GA), SLD43.5 (GA), SLD56.5 (GA), SLD71.5 (GA), SLD86.5 (GA)
red12: R12.2, SLD12.5 (GA), SLD27.5 (GA), SLD28.5 (GA), SLD42.5 (GA), SLD57.5 (GA), SLD72.5 (GA), SLD87.5 (GA)

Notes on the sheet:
Note that when wiring the LVC9 -> mainboard connector the BTN0 and BTN2 leads need to be swapped since the order is reversed here to simplify routing.
Wire LEDs using common anode.

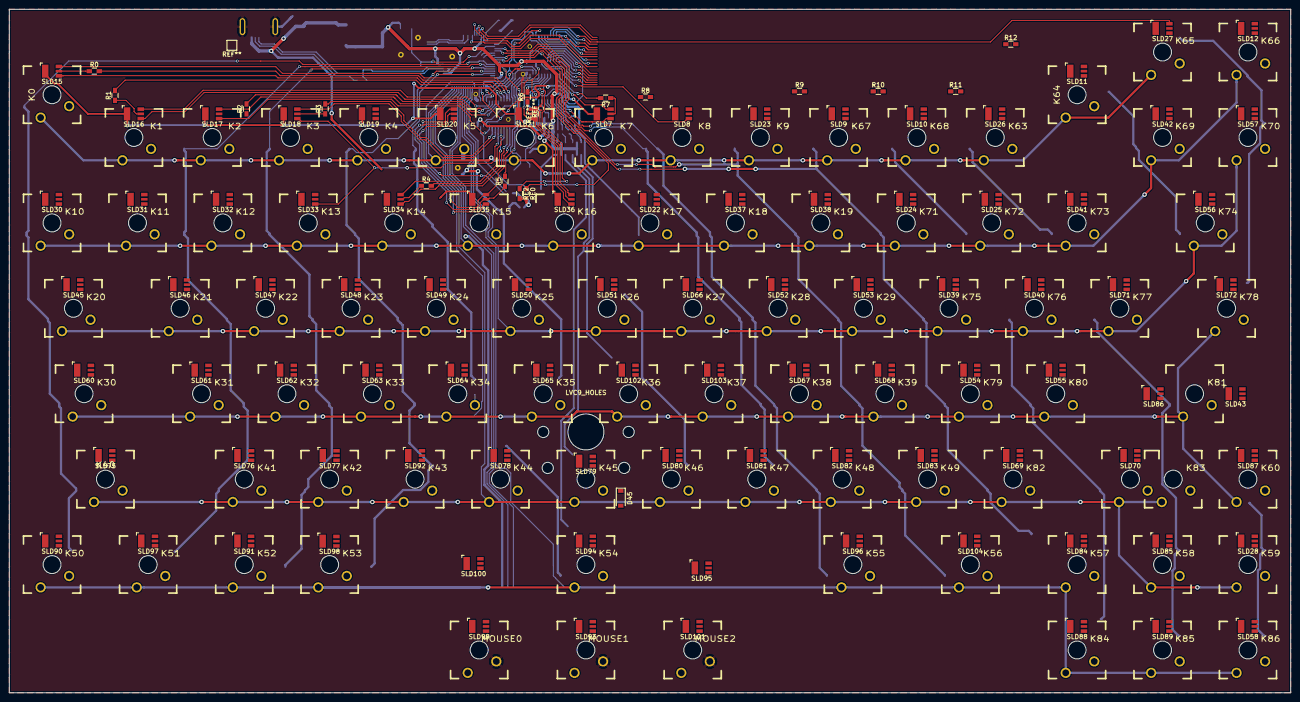
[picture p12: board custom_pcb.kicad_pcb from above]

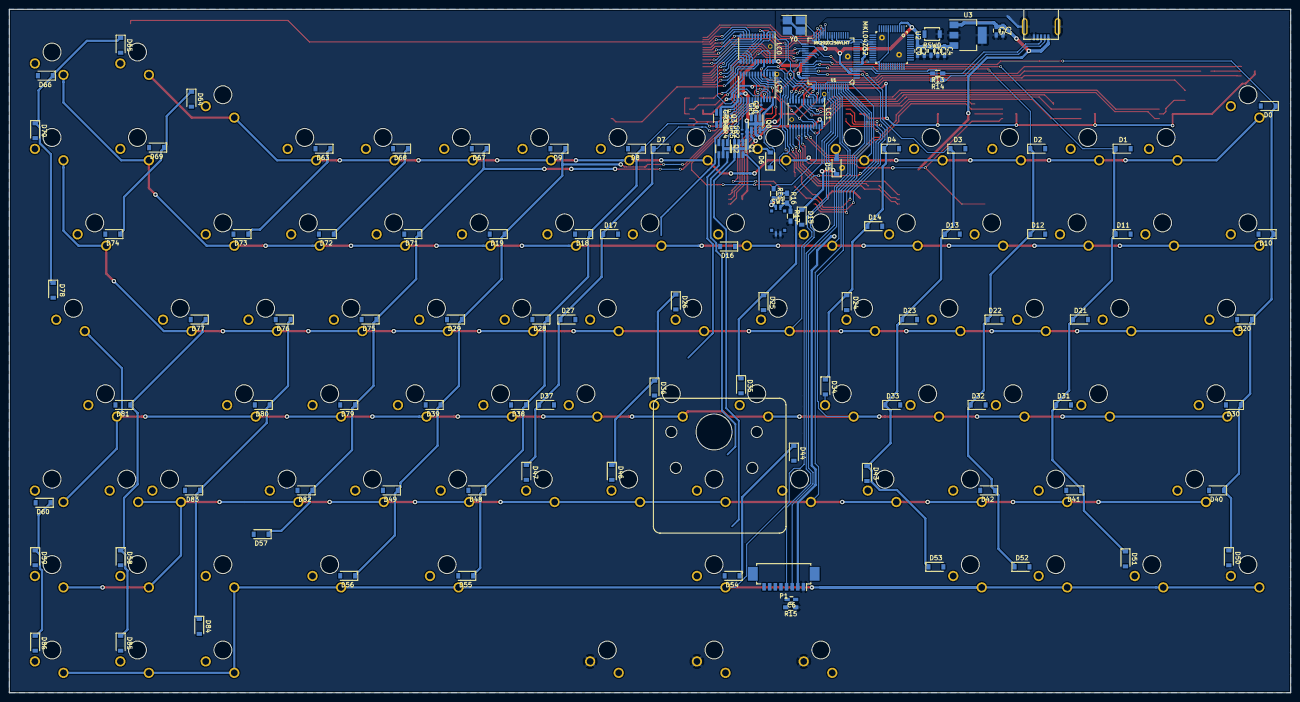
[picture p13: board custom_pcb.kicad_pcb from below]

Board: 2 copper layers, 285.0 x 152.0 mm, 324 parts (120 on the bottom side), 211 nets.

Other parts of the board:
LVC9_HOLES: LVC9 Attach; LVC9_HOLES

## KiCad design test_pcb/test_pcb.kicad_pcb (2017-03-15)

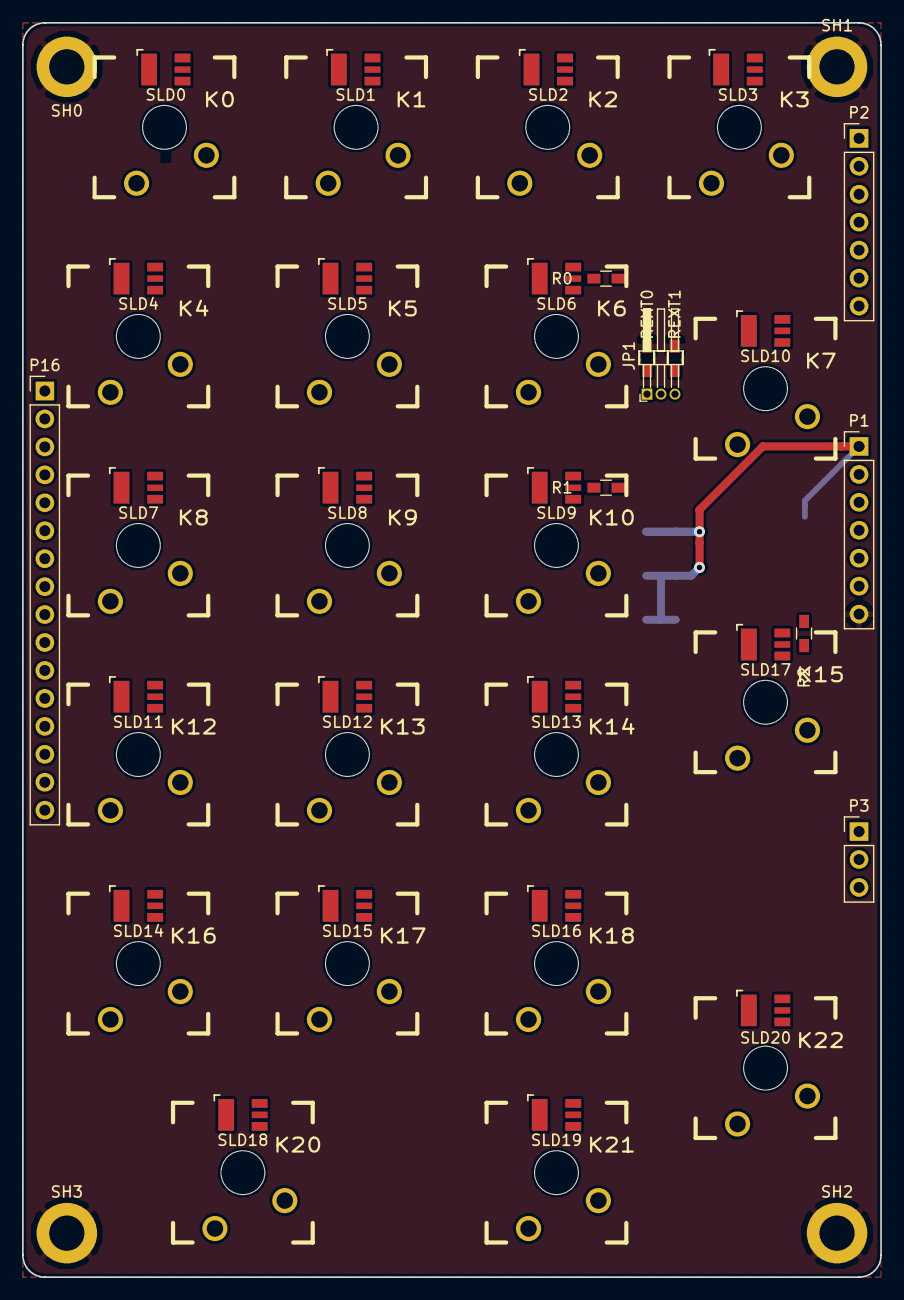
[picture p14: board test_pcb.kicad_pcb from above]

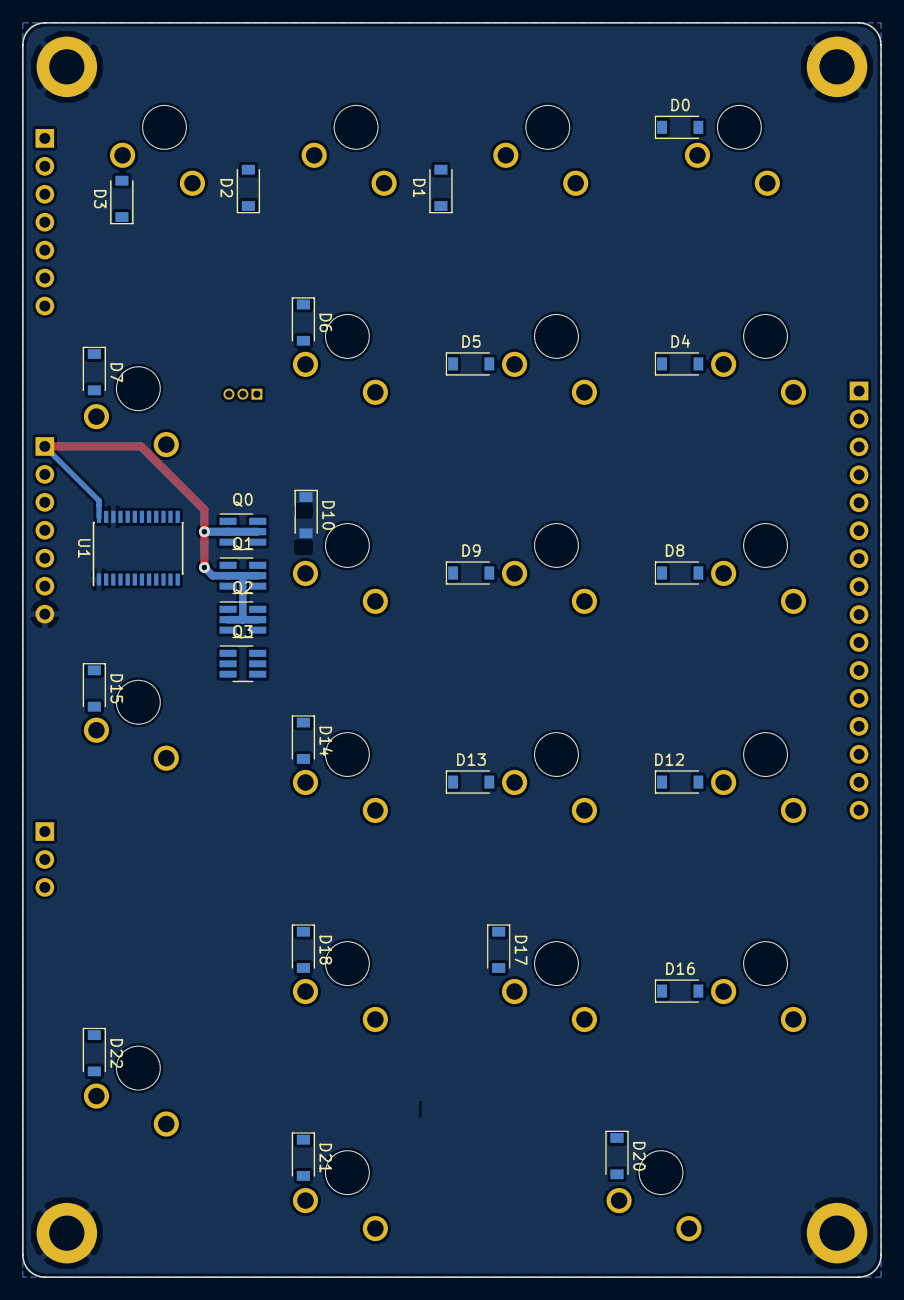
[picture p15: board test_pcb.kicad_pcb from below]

Board: 2 copper layers, 78.0 x 114.0 mm, 82 parts (26 on the bottom side), 66 nets.

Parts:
D0, D1, D2, D3, D4, D5, D6, D7, D8, D9, D10, D12, D13, D14, D15, D16, D17, D18, D20, D21, D22: D; D_SOD-123
JP1: Jumper_NC_Dual; Pin_Header_Angled_1x03_Pitch1.27mm
K0, K1, K2, K3: KEYSW; CHERRY_PLATE_91.6H
K4, K5, K6, K8, K9, K10, K12, K13, K14, K16, K17, K18, K21: KEYSW; CHERRY_PLATE_100H
K7, K15: KEYSW; CHERRY_PLATE_150V
K20: KEYSW; CHERRY_PLATE_200H
K22: KEYSW; CHERRY_PLATE_200V
P1, P2: CONN_01X07; Socket_Strip_Straight_1x07_Pitch2.54mm
P3: CONN_01X03; Socket_Strip_Straight_1x03_Pitch2.54mm
P16: CONN_01X16; Socket_Strip_Straight_1x16_Pitch2.54mm
Q0, Q1, Q2, Q3: Si3993CDV; SOT-23-6_Handsoldering
R0, R1, R2: R; R_0603_HandSoldering_label_right
REXT0, REXT1: R; R_0603_HandSoldering_label_right
SH0, SH1, SH2, SH3: CONN_01X01; MountingHole_3.2mm_M3_ISO14580_Pad
SLD0, SLD1, SLD2, SLD3, SLD4, SLD5, SLD6, SLD7, SLD8, SLD9, SLD11, SLD12, SLD13, SLD14, SLD15, SLD16, SLD18, SLD19, SLD20: SMLVN6RGB_CA
SLD10, SLD17: SMLVN6RGB; SMLVN6RGB_CA
U1: STP16CP05; TSSOP-24_4.4x7.8mm_Pitch0.65mm

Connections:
+3V3: P1.1, Q0.2, Q0.5, Q1.2, Q1.5, Q2.2, Q2.5, Q3.5, U1.24
CLK: P1.5, U1.3
GND: P1.7, REXT0.1, REXT1.1, SH0.1, SH1.1, SH2.1, SH3.1, U1.1, U1.22
LE: P1.4, U1.4
unnamed: D0.2, K0.2
unnamed: D1.2, K1.2
unnamed: D2.2, K2.2
unnamed: D3.2, K3.2
unnamed: D4.2, K4.2
unnamed: D5.2, K5.2
unnamed: D6.2, K6.2
unnamed: D7.2, K7.2
unnamed: D8.2, K8.2
unnamed: D9.2, K9.2
unnamed: D10.2, K10.2
unnamed: D12.2, K12.2
unnamed: D13.2, K13.2
unnamed: D14.2, K14.2
unnamed: D15.2, K15.2
unnamed: D16.2, K16.2
unnamed: D17.2, K17.2
unnamed: D18.2, K18.2
unnamed: D20.2, K20.2
unnamed: D21.2, K21.2
unnamed: D22.2, K22.2
unnamed: JP1.1, REXT0.2
unnamed: JP1.3, REXT1.2
unnamed: R0.2, U1.15
unnamed: R1.2, U1.16
unnamed: R2.2, U1.17
OE: P1.3, U1.21
SDI: P1.6, U1.2
a0: Q0.6, SLD0.1, SLD7.1, SLD14.1
a1: Q0.4, SLD1.1, SLD8.1, SLD15.1
a2: Q1.6, SLD2.1, SLD9.1, SLD16.1
a3: Q1.4, SLD3.1, SLD10.1, SLD17.1
a4: Q2.6, SLD4.1, SLD11.1, SLD18.1
a5: Q2.4, SLD5.1, SLD12.1, SLD19.1
a6: Q3.6, SLD6.1, SLD13.1, SLD20.1
as0: P16.7, Q0.1, U1.6
as1: P16.8, Q0.3, U1.7
as2: P16.9, Q1.1, U1.8
as3: P16.10, Q1.3, U1.9
as4: P16.11, Q2.1, U1.10
as5: P16.12, Q2.3, U1.11
as6: P16.13, Q3.1, U1.12
blue0: P16.1, SLD0.6, SLD1.6, SLD2.6, SLD3.6, SLD4.6, SLD5.6, SLD6.6, U1.20
blue1: P16.4, SLD7.6, SLD8.6, SLD9.6, SLD10.6, SLD11.6, SLD12.6, SLD13.6, U1.19
blue2: P16.14, SLD14.6, SLD15.6, SLD16.6, SLD17.6, SLD18.6, SLD19.6, SLD20.6, U1.18
c0: D0.1, D4.1, D8.1, D12.1, D16.1, D20.1, P2.1
c1: D1.1, D5.1, D9.1, D13.1, D17.1, P2.3
c2: D2.1, D6.1, D10.1, D14.1, D18.1, D21.1, P2.4
c3: D3.1, D7.1, D15.1, D22.1, P2.5
green0: P16.3, SLD0.4, SLD1.4, SLD2.4, SLD3.4, SLD4.4, SLD5.4, SLD6.4, U1.14
green1: P16.6, SLD7.4, SLD8.4, SLD9.4, SLD10.4, SLD11.4, SLD12.4, SLD13.4, U1.13
green2: P16.16, SLD14.4, SLD15.4, SLD16.4, SLD17.4, SLD18.4, SLD19.4, SLD20.4, U1.5
r0: K0.1, K1.1, K2.1, K3.1, P2.2
r1: K4.1, K5.1, K6.1, K7.1, P2.6
r2: K8.1, K9.1, K10.1, P2.7
r3: K12.1, K13.1, K14.1, K15.1, P3.1
r4: K16.1, K17.1, K18.1, P3.2
r5: K20.1, K21.1, K22.1, P3.3
red0: P16.2, R0.1, SLD0.5, SLD1.5, SLD2.5, SLD3.5, SLD4.5, SLD5.5, SLD6.5
red1: P16.5, R1.1, SLD7.5, SLD8.5, SLD9.5, SLD10.5, SLD11.5, SLD12.5, SLD13.5
red2: P16.15, R2.1, SLD14.5, SLD15.5, SLD16.5, SLD17.5, SLD18.5, SLD19.5, SLD20.5
rext: JP1.2, P1.2, U1.23

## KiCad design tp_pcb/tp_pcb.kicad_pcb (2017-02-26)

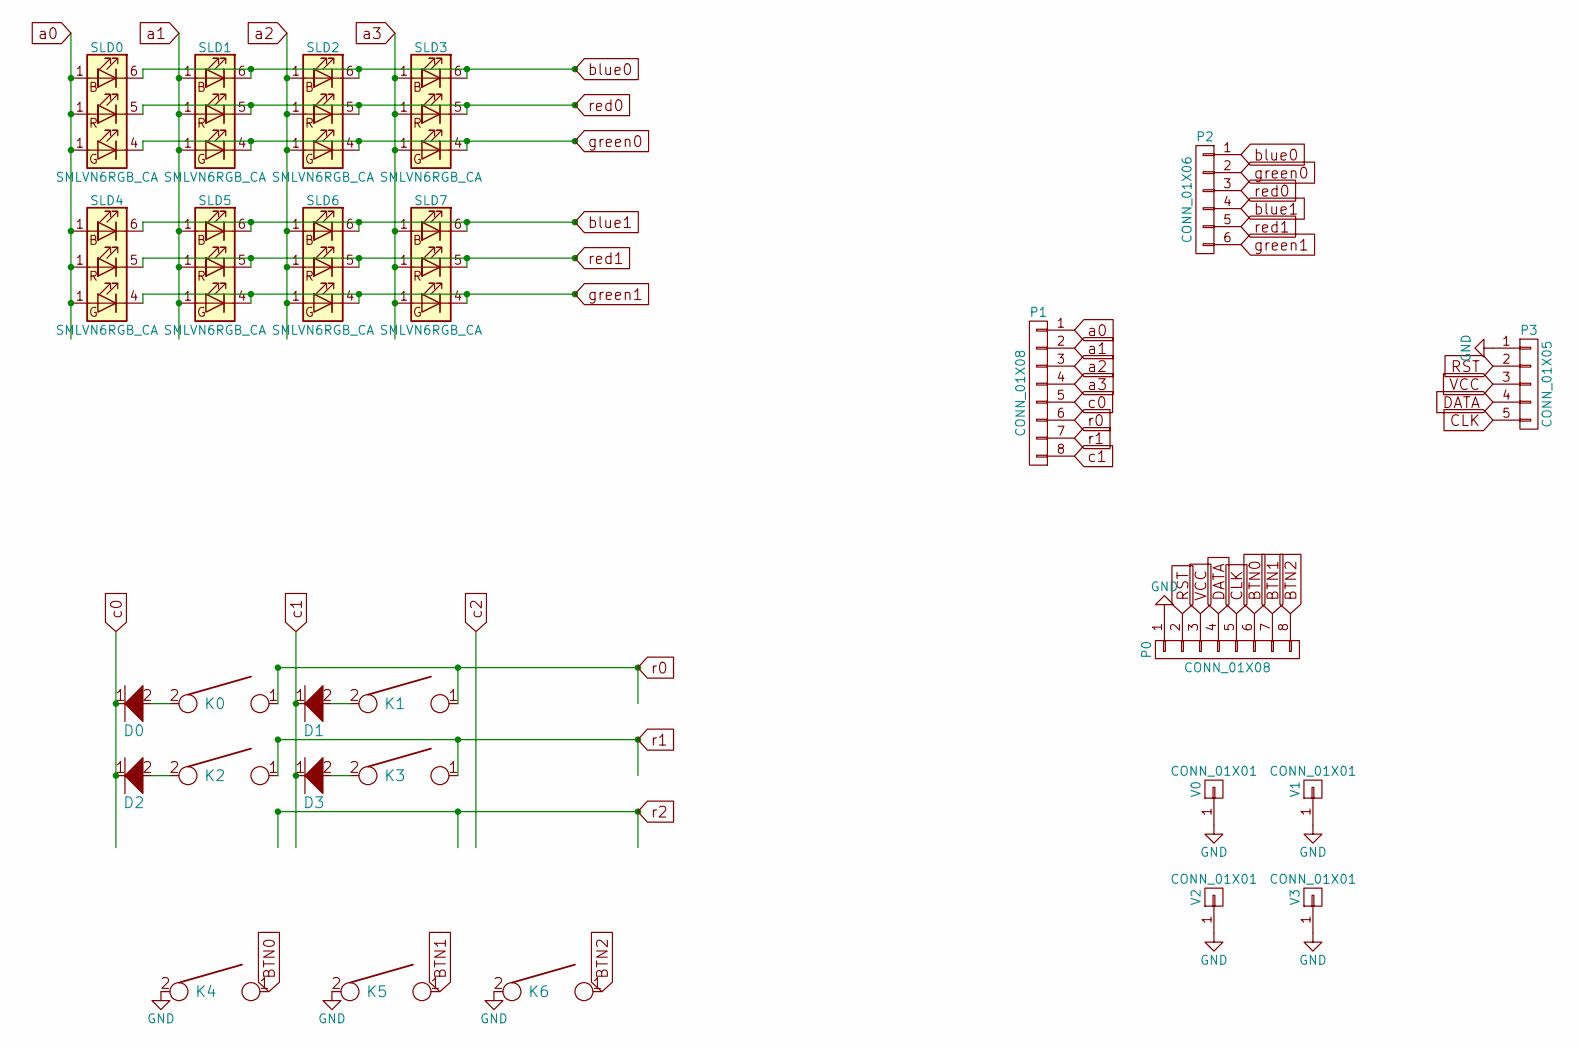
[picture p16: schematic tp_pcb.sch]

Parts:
D0, D1, D2, D3: D; D_SOD-123
K0, K1, K2, K5: KEYSW; CHERRY_PLATE_NH_100H
K3: KEYSW; CHERRY_PLATE_NH_5000H
K4, K6: KEYSW; CHERRY_PLATE_175H
P0: CONN_01X08; Molex_PicoBlade_53261-0871_08x1.25mm_Angled
P1: CONN_01X08; Socket_Strip_Straight_1x08_Pitch2.54mm
P2: CONN_01X06; Socket_Strip_Straight_1x06_Pitch2.54mm
P3: CONN_01X05; Socket_Strip_Straight_1x05_Pitch2.54mm
SLD0, SLD1, SLD2, SLD3, SLD4, SLD5, SLD6, SLD7: SMLVN6RGB_CA
V0, V1, V2, V3: CONN_01X01; VIA127

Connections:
BTN0: K4.1, P0.6
BTN1: K5.1, P0.7
BTN2: K6.1, P0.8
CLK: P0.5, P3.5
DATA: P0.4, P3.4
GND: K4.2, K5.2, K6.2, P0.1, P3.1, V0.1, V1.1, V2.1, V3.1
unnamed: D0.2, K0.2
unnamed: D1.2, K1.2
unnamed: D2.2, K2.2
unnamed: D3.2, K3.2
RST: P0.2, P3.2
VCC: P0.3, P3.3
a0: P1.1, SLD0.1 (BK), SLD4.1 (BK)
a1: P1.2, SLD1.1 (BK), SLD5.1 (BK)
a2: P1.3, SLD2.1 (BK), SLD6.1 (BK)
a3: P1.4, SLD3.1 (BK), SLD7.1 (BK)
blue0: P2.1, SLD0.6 (RA), SLD1.6 (RA), SLD2.6 (RA), SLD3.6 (RA)
blue1: P2.4, SLD4.6 (RA), SLD5.6 (RA), SLD6.6 (RA), SLD7.6 (RA)
c0: D0.1, D2.1, P1.5
c1: D1.1, D3.1, P1.8
green0: P2.2, SLD0.4 (BA), SLD1.4 (BA), SLD2.4 (BA), SLD3.4 (BA)
green1: P2.6, SLD4.4 (BA), SLD5.4 (BA), SLD6.4 (BA), SLD7.4 (BA)
r0: K0.1, K1.1, P1.6
r1: K2.1, K3.1, P1.7
red0: P2.3, SLD0.5 (GA), SLD1.5 (GA), SLD2.5 (GA), SLD3.5 (GA)
red1: P2.5, SLD4.5 (GA), SLD5.5 (GA), SLD6.5 (GA), SLD7.5 (GA)

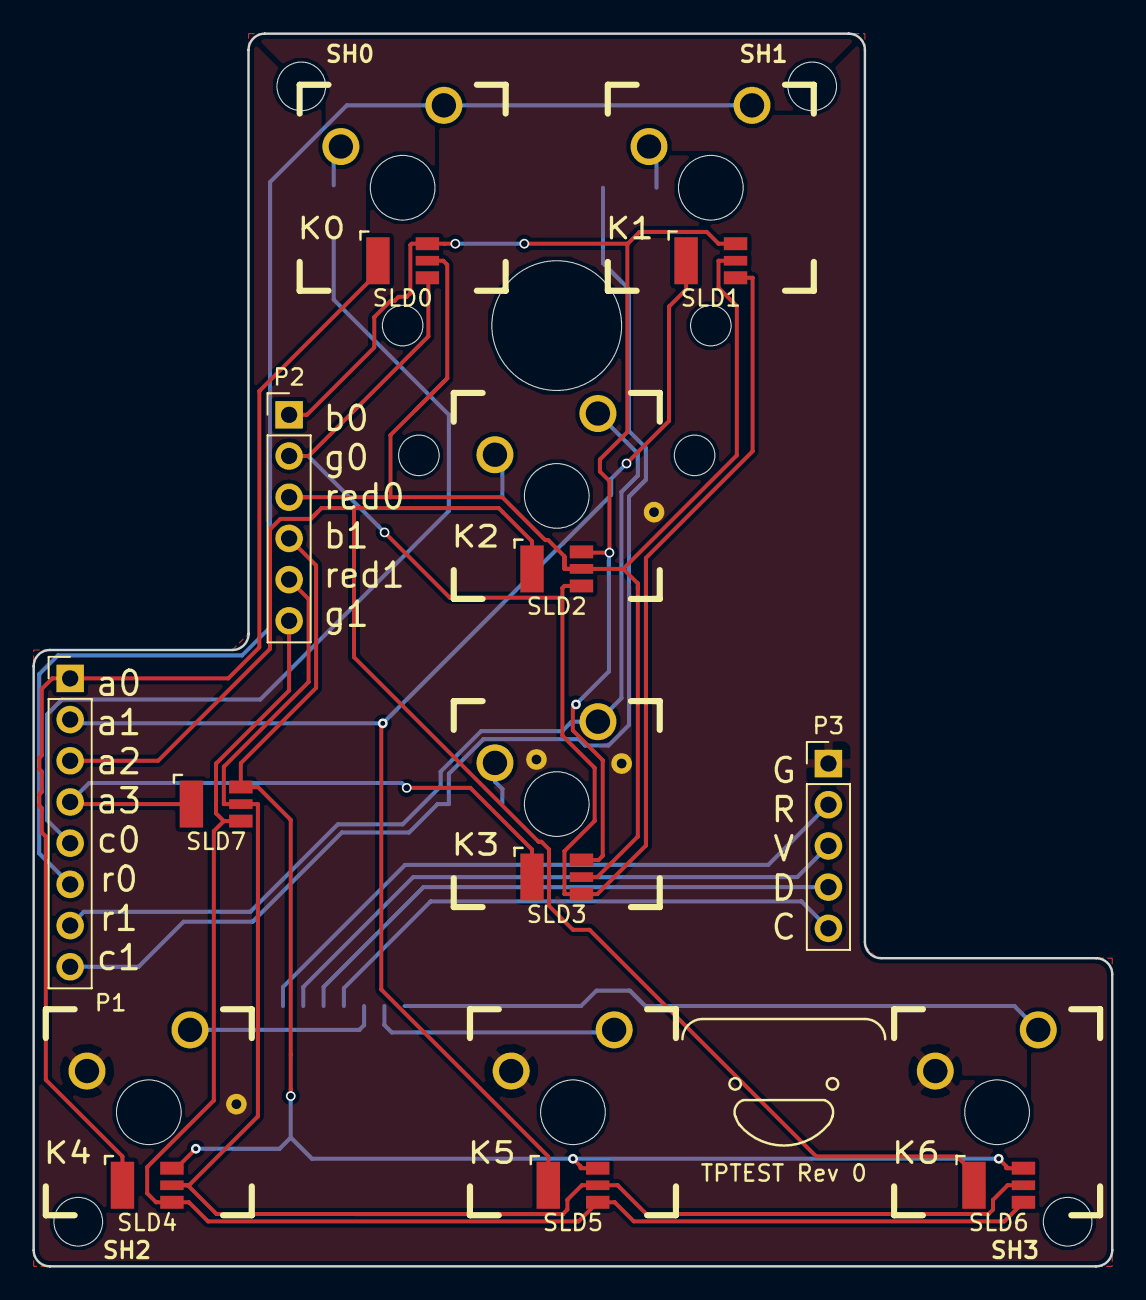
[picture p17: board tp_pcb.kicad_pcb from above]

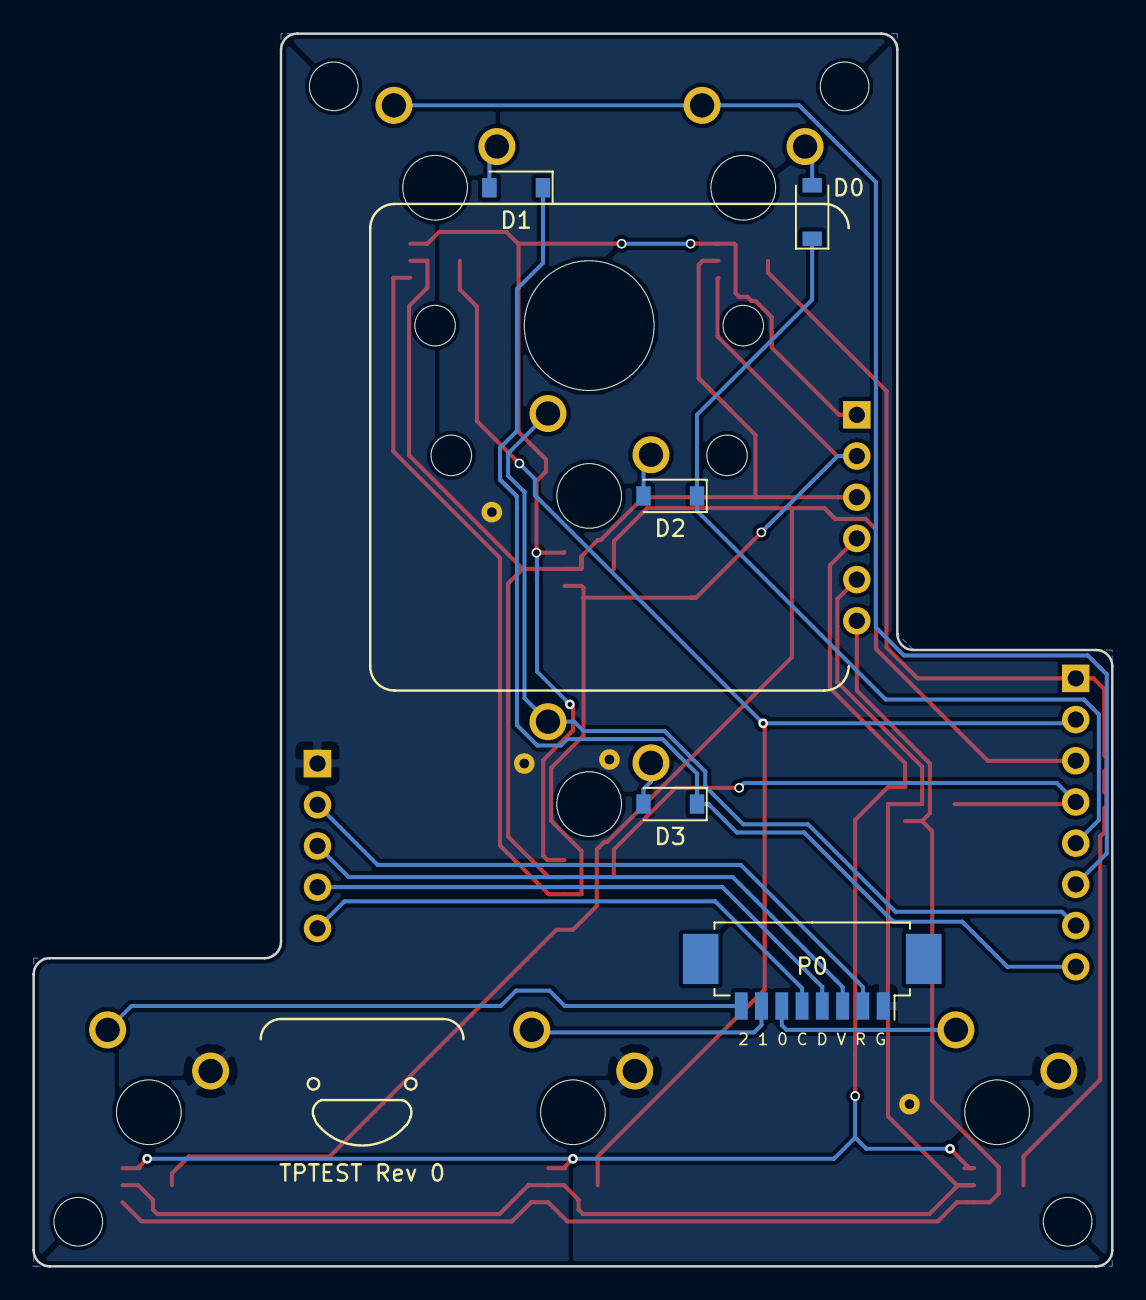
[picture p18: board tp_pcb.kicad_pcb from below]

Board: 2 copper layers, 66.5 x 76.0 mm, 34 parts (6 on the bottom side), 26 nets.

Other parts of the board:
LVC9_HOLES: LVC9 Attach; LVC9_HOLES_for_tptest
SH0, SH1, SH2, SH3: CONN_01X01; MOUNTING_HOLE
TPTEST Rev 0, TPTEST Rev 0#2: tgbugs_sig

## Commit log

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2017-02-03 added custom_pcb kicad project
    [custom_pcb.kicad_pcb, custom_pcb.sch]
2017-02-03 added test_pcb kicad project
    [test_pcb.kicad_pcb, test_pcb.sch]
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2017-02-06 test_pcb first pass complete
    [test_pcb.kicad_pcb, test_pcb.sch]
2017-02-06 custom_pcb first pass layout
    [custom_pcb.kicad_pcb]
2017-02-06 custom_pcb wiring and diode placement
    [custom_pcb.kicad_pcb]
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2017-02-06 cpcb shifted diodes down 1mm to make routing rows easier
    [custom_pcb.kicad_pcb]
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2017-02-07 cpcb switched to 7x14 matrix finished first pass routing
    [custom_pcb.kicad_pcb, custom_pcb.sch]
2017-02-07 cpcb routing of rows and columns complete
    [custom_pcb.kicad_pcb, custom_pcb.sch]
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2017-02-07 cpcb started led work
    [custom_pcb.kicad_pcb, custom_pcb.sch]
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2017-02-07 cpcb major improvements to trackpoint routing
    [custom_pcb.kicad_pcb, custom_pcb.sch]
2017-02-07 finished 2nd draft led wiring
    [custom_pcb.kicad_pcb, custom_pcb.sch]
2017-02-08 cpcb some cleanup of keys, offset by top routing getting messed up (needs to be reworked anyway), plus experiments on how to route individual BRG rows, need to experiment with all of a single color r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
    [custom_pcb.kicad_pcb, custom_pcb.sch]
2017-02-08 cpcb routing all same color turns out to be a much better idea, plus sync errors will appear to be shifts in hue rather than shifts in timing
    [custom_pcb.kicad_pcb]
2017-02-08 cpcb we dont need the diodes all the way up, much more room if hidden near the hole, only works at the margins
    [custom_pcb.kicad_pcb]
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2017-02-08 cpcb routing of blue traces and reworing of upper anodes
    [custom_pcb.kicad_pcb, custom_pcb.sch]
2017-02-09 cpcb improved routing of annodes and columns on the right side of the board
    [custom_pcb.kicad_pcb]
2017-02-09 LED_CLK routing and placement of the LED drivers so that they are all at the end of a 37mm track
    [custom_pcb.kicad_pcb, custom_pcb.sch]
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2017-02-10 routing tweaks to free up more space for reimplementing the teensy
    [custom_pcb.kicad_pcb]
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2017-02-10 test experiment with 11/12ths keys
    [test_pcb.kicad_pcb]
2017-02-10 all traces for the matrix are done
    [custom_pcb.kicad_pcb, custom_pcb.sch]
2017-02-10 equalized led clk distances
    [custom_pcb.kicad_pcb]
2017-02-10 started work on ground planes and rerouting the led tracks so that the via is on the anode saving 4 vias per led
    [custom_pcb.kicad_pcb, custom_pcb.sch]
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2017-02-13 test is now a numpad for led testing + a 6 key test for the trackpoint
    [test_pcb.kicad_pcb, test_pcb.sch]
2017-02-13 lots of progress on numpad
    [test_pcb.kicad_pcb, test_pcb.sch]
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2017-02-14 when you use a contant current LED driver you don't actually need resistors!
    [test_pcb.kicad_pcb, test_pcb.sch]
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2017-02-21 added tp_pcb for prototyping the trackpoint part of the board
    [tp_pcb.kicad_pcb, tp_pcb.sch]
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2017-02-24 cpcb freerouting files prior to completely reworking the circuitry
    [custom_pcb.dsn, custom_pcb_routed.dsn]
2017-02-24 cpcb wrote the output of freerouting for the record
    [custom_pcb.kicad_pcb]
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2017-02-25 test pcb freerouting is bugged on this right now
    [test_pcb.dsn, test_pcb.kicad_pcb, test_pcb.sch]
2017-02-25 test pcb some improvement, but still getting the infinite fails
    [test_pcb.dsn, test_pcb.kicad_pcb, test_pcb.sch]
2017-02-25 test pcb seem to have fixed the routing bug
    [test_pcb.dsn, test_pcb.kicad_pcb, test_pcb.sch]
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2017-02-25 test somehow improved routing adding 5 more and 1mm on the right side of the board
    [test_pcb.dsn, test_pcb.kicad_pcb, test_pcb.sch]
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2017-02-25 added flipped angled 01x02 header footprint
    [test_pcb.kicad_pcb]
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2017-02-26 test added 1mm to left to match that on right
    [test_pcb.kicad_pcb]
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2017-02-26 libs updated to shorten led name
2017-02-26 removed old project and sch, saving sch before rename
    [_saved_test_pcb.sch]
2017-02-26 led footprints updated so that silkscreen doesn't hit the nogo zone
2017-02-26 renaming leds and swapping footprints
    [test_pcb.kicad_pcb, test_pcb.sch]
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2017-02-26 test mouting holes and sch cleanup and notes
    [test_pcb.kicad_pcb, test_pcb.sch]
2017-02-26 footprints, signature and led orientation marking, added to board
    [test_pcb.kicad_pcb]
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2017-02-26 test NUMPAD rev 0 files which are to be submitted for fabrication
    [test_pcb-B.Cu.gbl, test_pcb-B.Mask.gbs, test_pcb-B.Paste.gbp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]
2017-02-26 tp major improvements + routing, tp holes improved and modified
    [tp_pcb.dsn, tp_pcb.kicad_pcb, tp_pcb.sch]
2017-02-26 tp fixed naming issues
    [tp_pcb.kicad_pcb, tp_pcb.sch]
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2017-02-26 spacebar silkscreen fix
    [tp_pcb.kicad_pcb]
2017-02-26 tp silkscreen touchup and a few final tweaks
    [tp_pcb.kicad_pcb, tp_pcb.sch]
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2017-02-26 tp some very minor change that was probably in rev0
    [tp_pcb.kicad_pcb]
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2017-02-27 logic and gerber was missing drill files!
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2017-02-27 cpcb lots more relestate down at the bottom for the control circuitry
    [custom_pcb.dsn, custom_pcb.kicad_pcb, custom_pcb.sch]
2017-02-27 this is going to be tricky until the matrix is rewired correctly to minimize distance, also if we cut out the lower part of the pcb we won't have all this space, so we may ultimately go back to the p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
    [custom_pcb.dsn, custom_pcb.kicad_pcb]
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2017-03-07 test first pass manual routing of anodes for rev 1
    [test_pcb.dsn, test_pcb.kicad_pcb, test_pcb.sch]
2017-03-07 test routing complete, this is a pre application checkpoint
    [test_pcb.dsn, test_pcb.kicad_pcb]
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2017-03-07 cpcb starting to rework led positioning to minimize wiring
    [custom_pcb.kicad_pcb, custom_pcb.sch]
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2017-03-08 added other teensy 3.2 parts, left out a bunch of the analog stuff
    [custom_pcb.dsn, custom_pcb.kicad_pcb, custom_pcb.sch]
2017-03-08 cpcb timepoint before major led routing rework
    [custom_pcb.dsn, custom_pcb.kicad_pcb, custom_pcb.sch]
2017-03-08 removed old routed dsn file that is no longer part of the workflow
    [custom_pcb_routed.dsn]
2017-03-08 routing of the tricky bits and discovered and added the MKL04Z32
    [custom_pcb.dsn, custom_pcb.kicad_pcb, custom_pcb.sch]
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2017-03-08 cpcb and footprints updated for major reworking (all switches rotated 180, thanks ducky\!)
    [custom_pcb.kicad_pcb]
2017-03-08 small fixes and checkpoint for moving the leds
    [custom_pcb.kicad_pcb, custom_pcb.sch]
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2017-03-09 flipped keys that were previously missed
    [custom_pcb.kicad_pcb, custom_pcb.sch]
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2017-03-09 keyboard matrix layout fixed
    [custom_pcb.kicad_pcb, custom_pcb.sch]
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2017-03-09 was missing latch
    [custom_pcb.dsn, custom_pcb.kicad_pcb]
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2017-03-09 issue was inaccessible track on sld79
    [custom_pcb.dsn, custom_pcb.kicad_pcb]
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2017-03-10 first pass at fixing lc0 pinout ordering
    [custom_pcb.dsn, custom_pcb.kicad_pcb, custom_pcb.sch]
2017-03-10 gp and row ordering bug
    [custom_pcb.kicad_pcb, custom_pcb.sch]
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2017-03-10 push routing mode is dangerous, it can move tracks into positions that cause infinite looping in freerouter because they block all ways to access a pad
    [custom_pcb.dsn, custom_pcb.kicad_pcb, custom_pcb.sch]
2017-03-10 seems that there was a connected/disconnected track that was causing bugs
    [custom_pcb.dsn, custom_pcb.kicad_pcb]
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2017-03-10 fixed crystal ground plane to match https://www.pjrc.com/store/ic_mkl02.html and https://forum.pjrc.com/threads/27397-Teensy-gt-Production?p=60903&viewfull=1#post60903
    [custom_pcb.kicad_pcb]
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2017-03-11 major rerouting to avoid any signals near the crystal and to get the rext resistors away from the led drivers
    [custom_pcb.kicad_pcb, custom_pcb.sch]
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2017-03-11 about the move the mcu a few units to the left to free up some space
    [custom_pcb.kicad_pcb, custom_pcb.sch]
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2017-03-11 found a better way to get power and anodes around
    [custom_pcb.dsn, custom_pcb.kicad_pcb, custom_pcb.sch]
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2017-03-15 test new footprints (the 180 variety) and new design rules
    [test_pcb.dsn, test_pcb.kicad_pcb, test_pcb.sch]
2017-03-15 logic for rest in parallel, but ultimately go with series since the setup is safer if the attempt fails, also consdering trying to put everything on the front for real smd
    [custom_pcb.dsn, custom_pcb.kicad_pcb, custom_pcb.sch]
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2017-03-17 tweak was correct this time >_<
    [custom_pcb.dsn, custom_pcb.kicad_pcb]
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2017-03-17 determining power and figured out that for usb c we need a thing called a configuration channel (cc) control logic
    [custom_pcb.kicad_pcb, custom_pcb.sch]
2017-03-17 reworked power and did some routing that could make it possible to control the led output levels using transistors as switches instead of the dip switch, dependent on getting the usb c cc working
    [custom_pcb.kicad_pcb, custom_pcb.sch]
2017-03-30 ah gate resistors, why did no one tell me about you, solution is 402
    [custom_pcb.kicad_pcb, custom_pcb.sch]
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2018-08-03 v9 layout
    90 switches
    media keys, normal width fkeys, swapable f12/delete, tiny right shift
